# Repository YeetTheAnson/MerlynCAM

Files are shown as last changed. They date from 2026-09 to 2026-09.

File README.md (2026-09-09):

# MerlynCAM

## Introduction
This project was made possible thanks the reverse engineering efforts done by the OpenIPC team! You can check out their supported hardware here: https://openipc.org/supported-hardware/featured and the reference project here: https://oshwlab.com/oshwhub.com/openipc-vtx-ssc338q-30kq

This is my custom action camera, the MerlynCAM! This project was made to record HD footage on my FPV drones. It records video at 1080p@90, 1440p@60 and 4k@20. It also includes a BMI270 gyro to log motion data at 150Hz for Gyroflow video stabilization, and an ICS-43434 I2S microphone to capture propeller noise for the viewer's immersion.

The MerlynCAM is powered by the Sigmastar SSC338Q SOC. It is easy to use and includes a low power microcontroller onboard to manage the LED indicators, buttons, and power saving modes. There is only one button used for powering the camera on and off and starting and stopping recordings. The microcontroller handles the rest of the quality of life features in the background, such as battery level monitoring and auto power on when external voltage is detected in FPV mode. It also has an internal 1S battery with a BQ25606 charging circuit, so it can be used like a normal action cam or with the batteries removed to save weight on a drone.

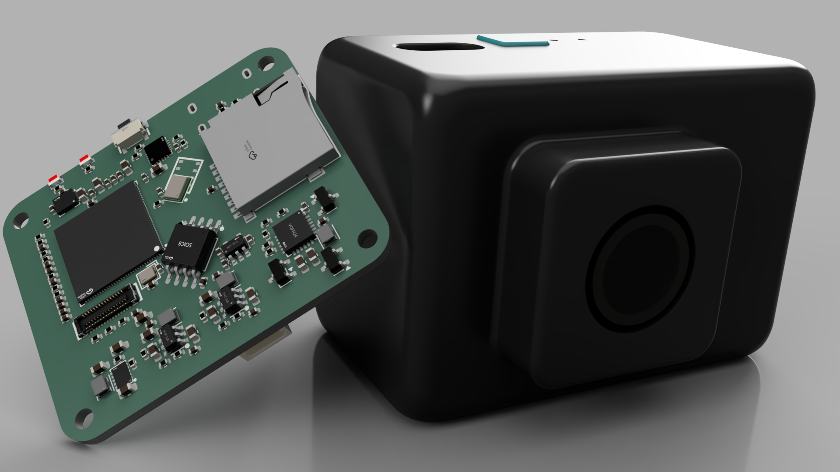
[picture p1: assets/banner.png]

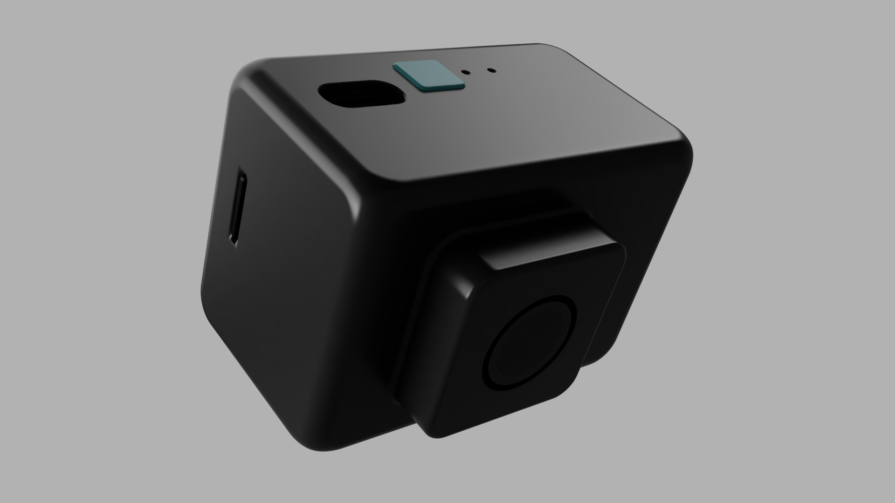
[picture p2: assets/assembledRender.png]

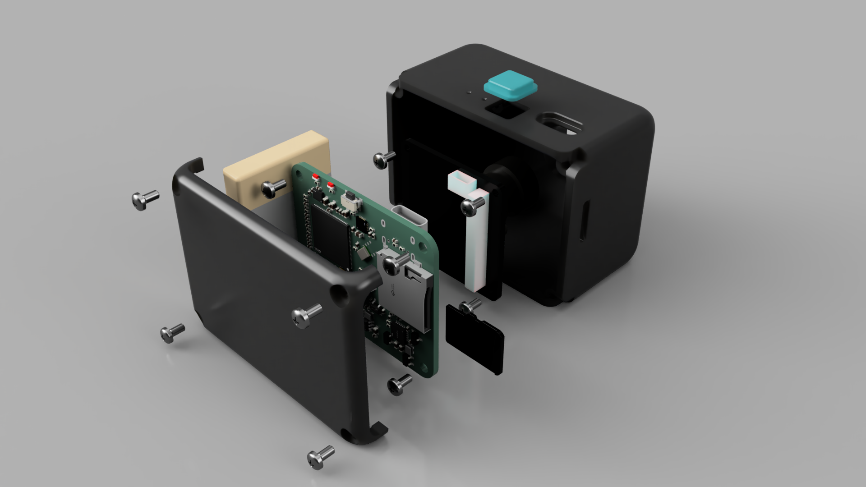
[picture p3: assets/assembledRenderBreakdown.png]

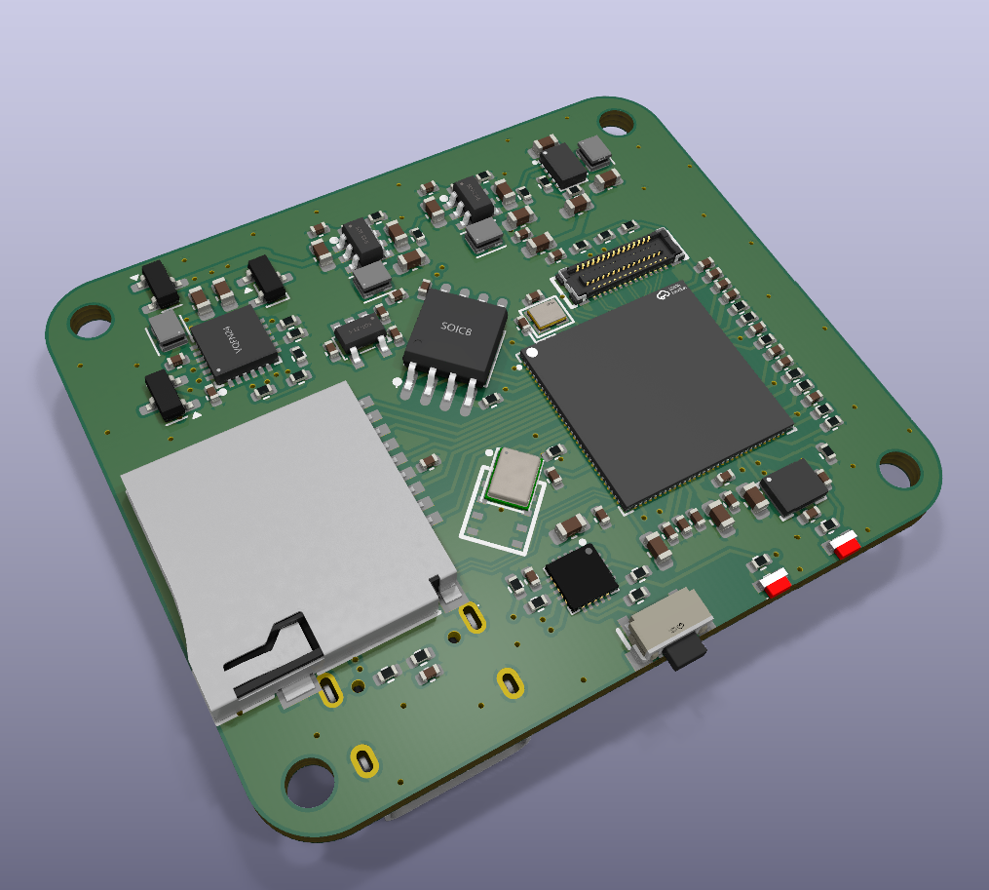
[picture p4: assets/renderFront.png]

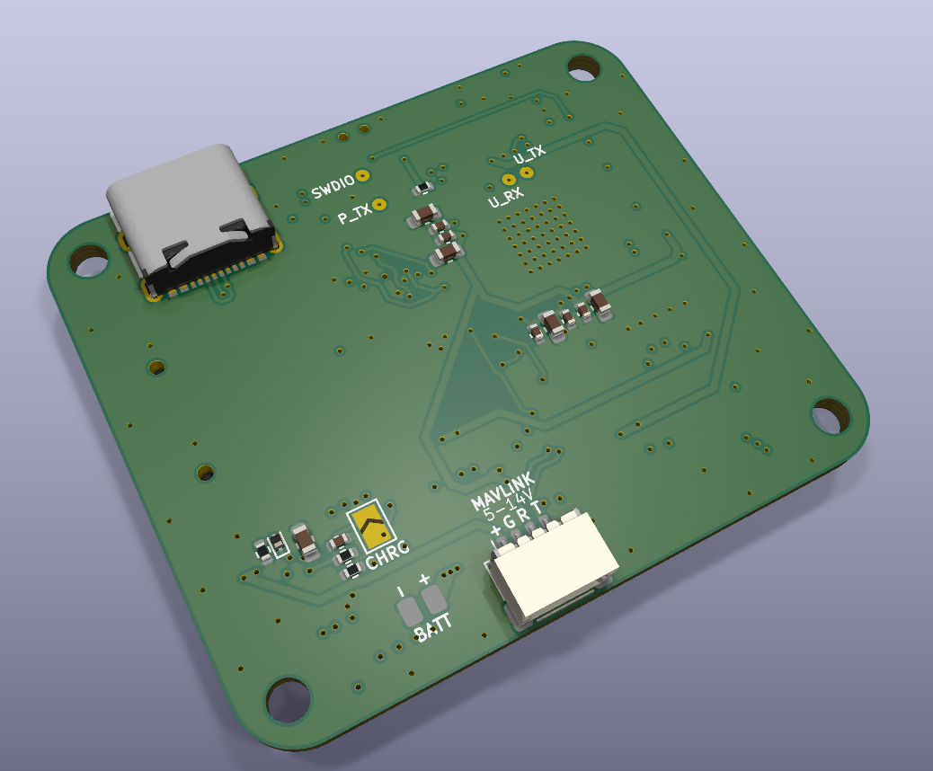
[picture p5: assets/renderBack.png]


## User Guide
The MerlynCAM is operated using a single button and it shows charge status and battery levels using a White LED

### Power & Recording Control
- **Power On:** Press the button once, then press and hold for 2 seconds. The White LED will blink rapidly while holding, then turn solid to indicate it is booting. Release the button afterwards.

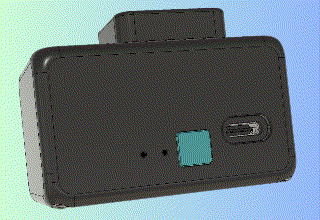
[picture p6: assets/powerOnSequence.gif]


> [!TIP]
> The camera will refuse to power on if the battery is below 5%

- **Power Off:** Press and hold the button for 4 seconds. The White LED will blink rapidly after 2 seconds, then blink twice and turn off.

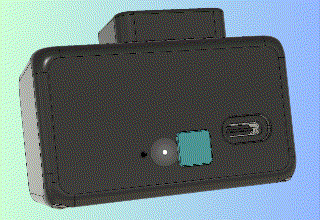
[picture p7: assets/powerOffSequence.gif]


- **Start/Stop Recording:** While the camera is powered on, hold the button for 1 second to start recording. Hold for 1 second again to stop recording.



### Battery Level Checking
While powered off, press the button once. The White LED will blink to indicate the current charge level:

- **\>95%:** 4 normal blinks + 3 rapid blinks



- **80-95%** 4 blinks



- **60-79%:** 3 blinks



- **40-59%:** 2 blinks



- **20-39%:** 1 blink



- **\< 5%:** 3 rapid blinks



### Passive Indicator
- **Charging:** The white LED will pulse slowly while charging. Once fully charged, it will remain solid until the power is disconnected

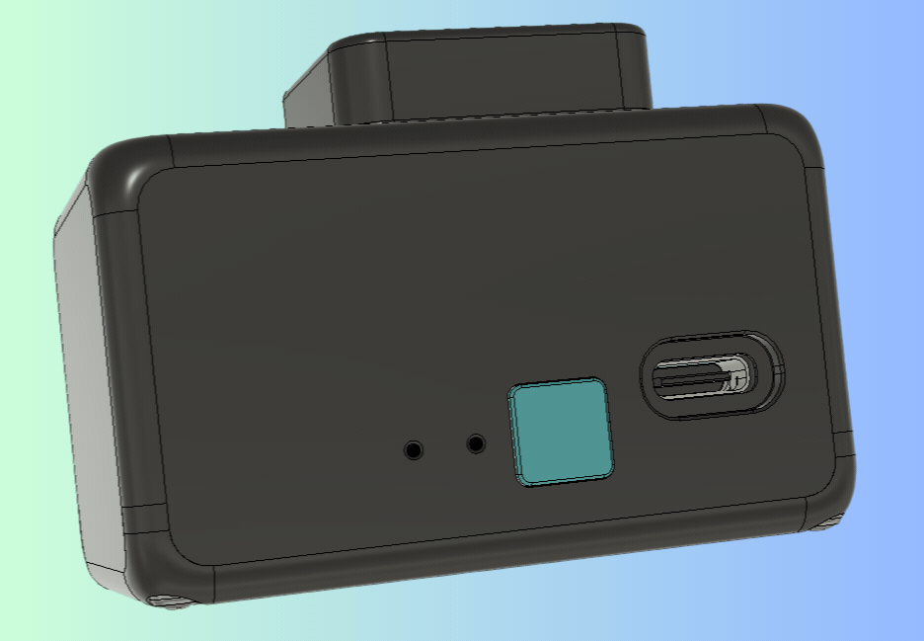
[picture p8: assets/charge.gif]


- **Battery Status:** The White LED automatically flashes the current battery percentage every 3.5 seconds

> [!IMPORTANT]
> Bridge the CHRG pad on the PCB if no battery is connected. This is necessary for the battery management IC to output a stable voltage on external power.

## Hardware Specifications
* **SOC:** Sigmastar SSC338Q
* **Camera Interface:** 30 pin mezzanine connector (compatible with Orange Pi 5)
* **IMU:** BMI270 @ I2C
* **Microphone:** ICS-43434 @ I2S
* **Storage:** Micro SD Card slot + W25Q128JVSIQ 16MB NOR Flash
* **Power Management & User Interface:** CH32V003F4U6
* **Battery Management:** BQ25606
* **Power Supply:** TPS63802 buck boost (3.3V), RT8097CHGE buck (1.0V and 1.5V), RT9193-18GB LDO (1.8V)

## Hardware Overview
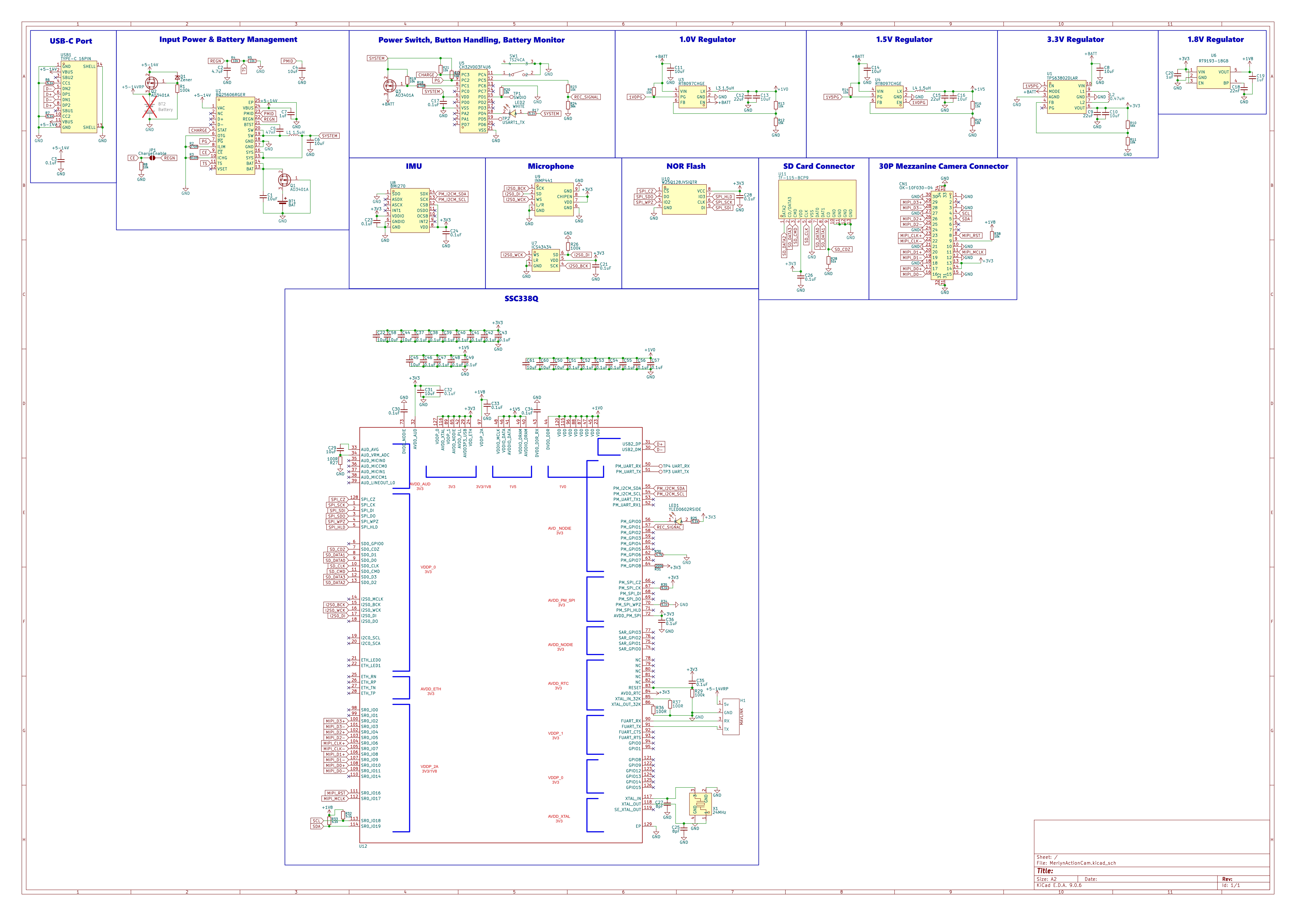
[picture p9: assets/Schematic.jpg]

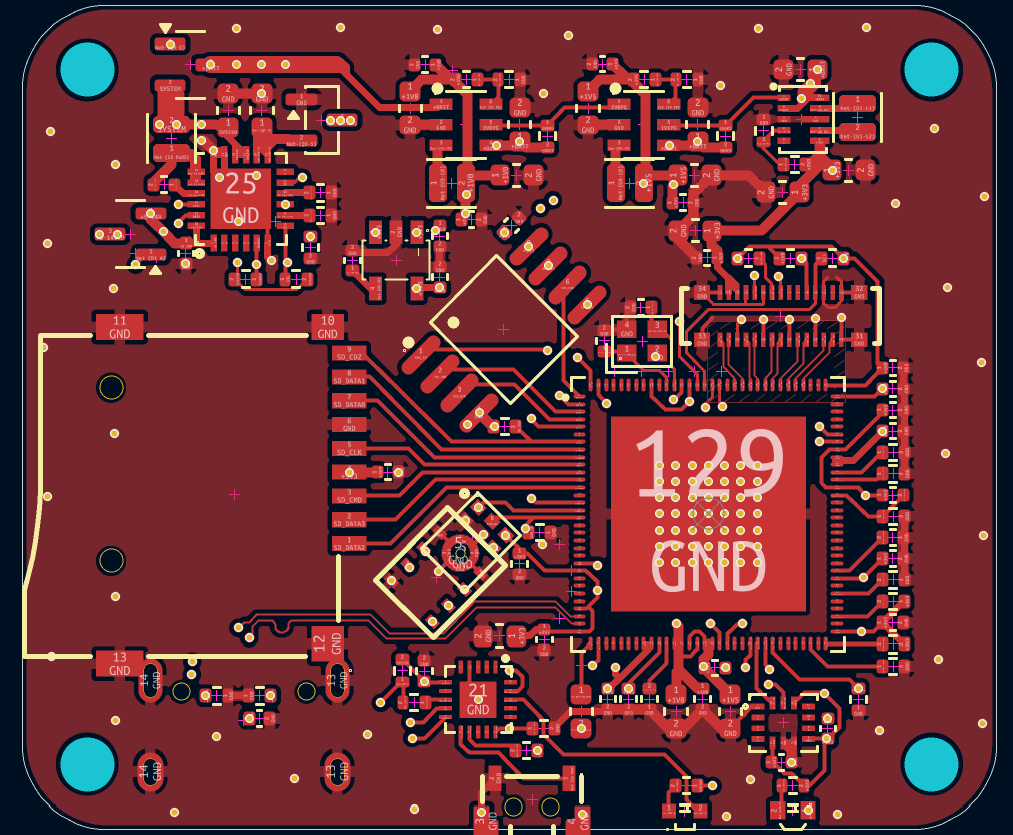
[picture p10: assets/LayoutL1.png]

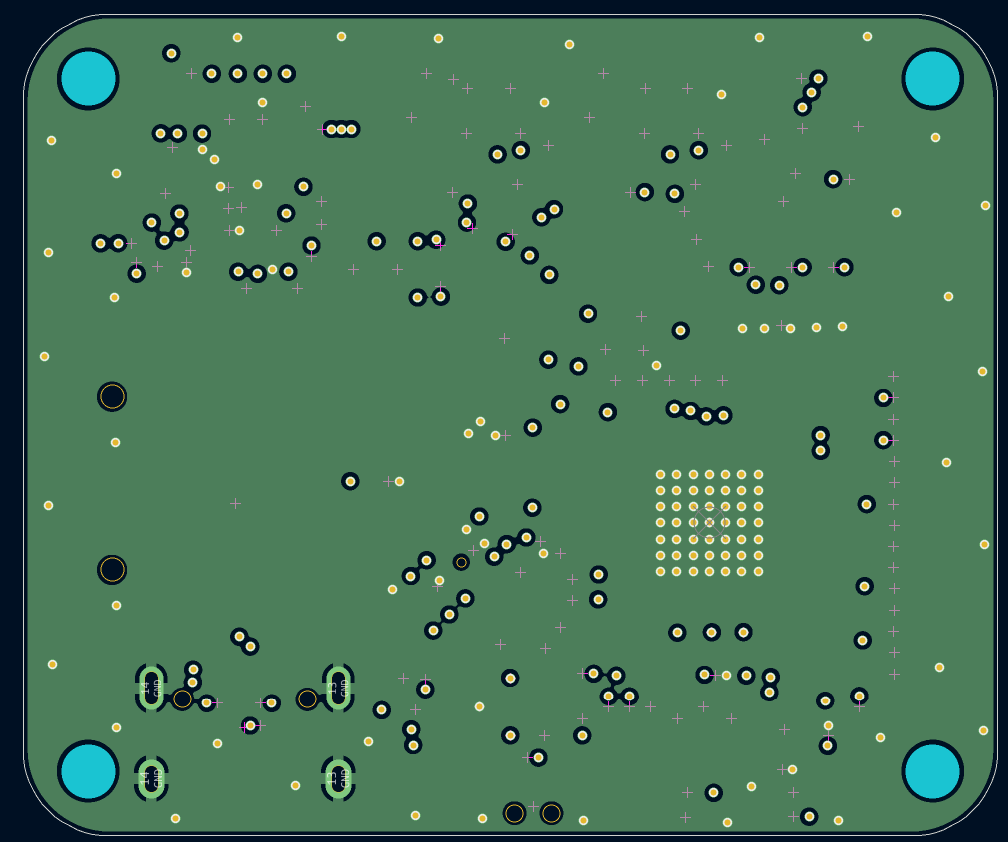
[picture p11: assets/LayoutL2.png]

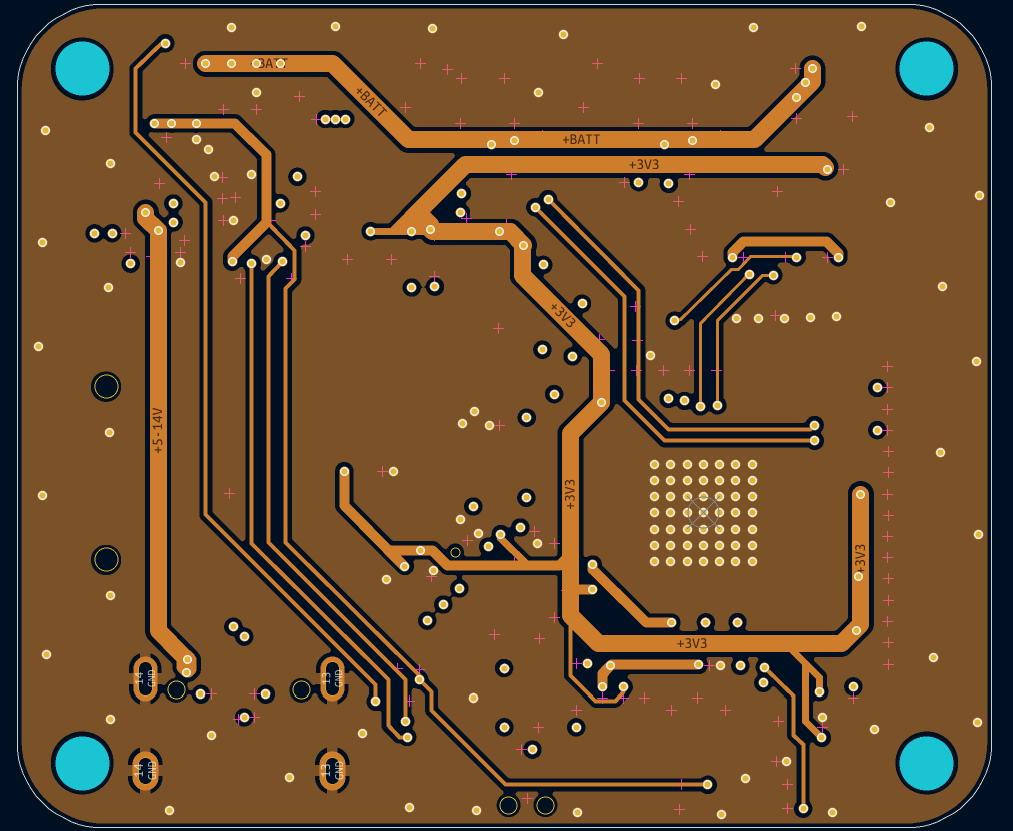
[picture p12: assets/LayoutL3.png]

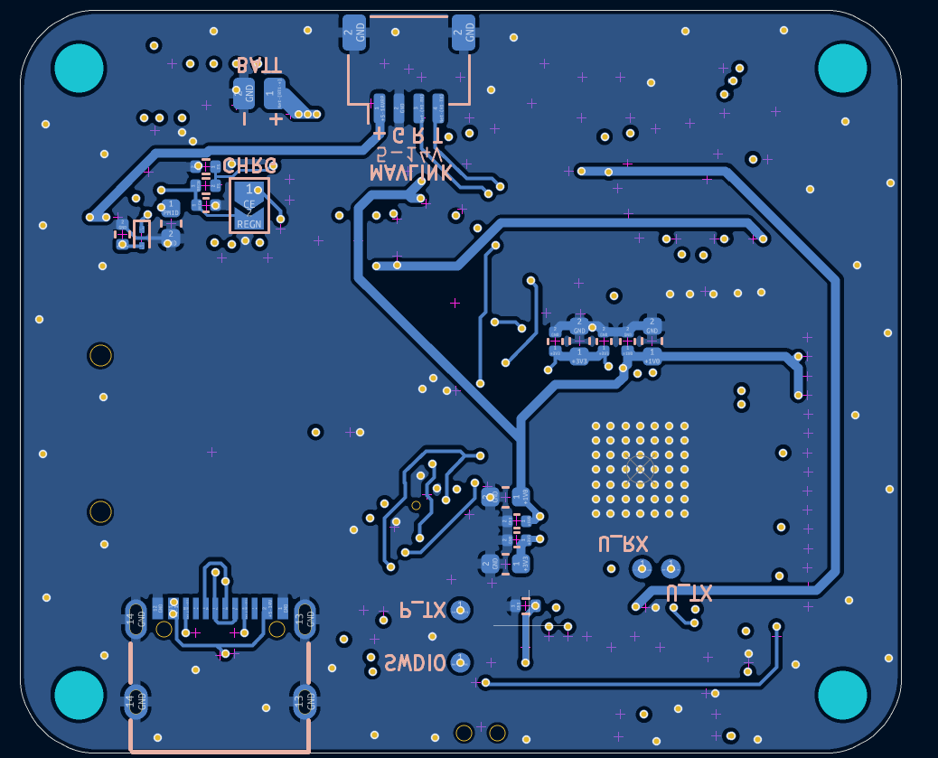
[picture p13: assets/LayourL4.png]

> [!WARNING]
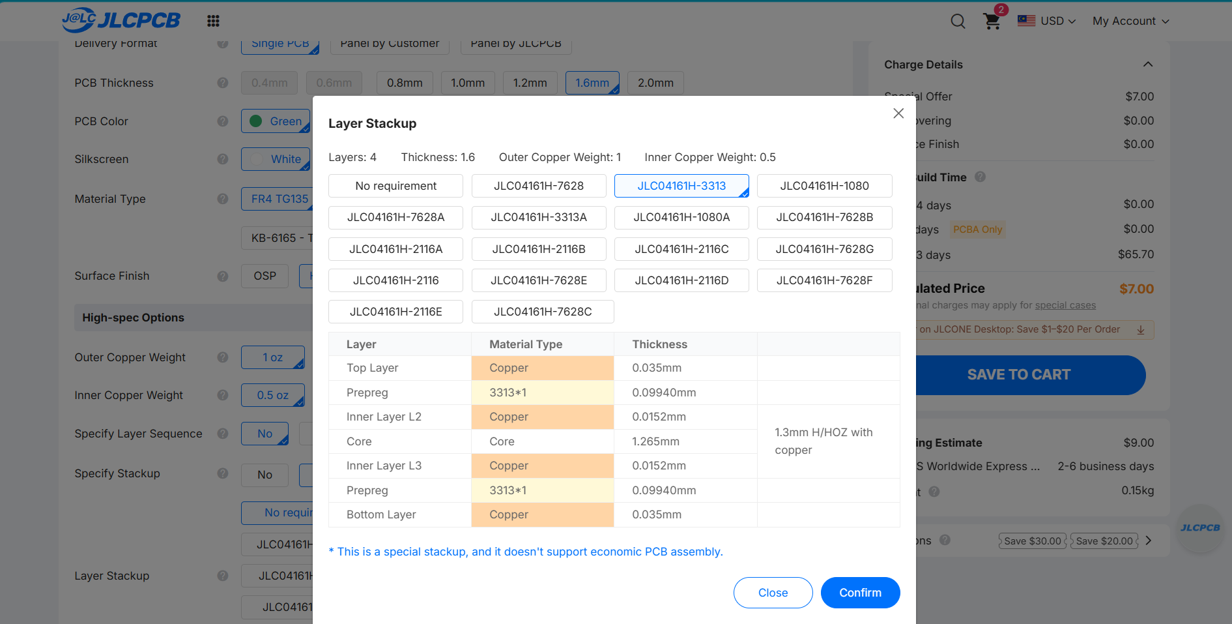
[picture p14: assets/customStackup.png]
> When ordering from JLCPCB, make sure to enable impedance control and use the JLC04161H-3313 Stackup 

## Firmware
Because the SSC338Q is a proprietary chip, it must run the OpenIPC linux environment. Building the firmware requires a linux filesystem (Windows isn't supported)

> [!WARNING]
> At least 20GB of free space is required to build OpenIPC

### How to build the firmware (SSC338Q)
1. Clone the OpenIPC [firmware repository](https://github.com/openipc/firmware)
2. Run `make` and select the infinity6e architecture on the TUI.
3. Navigate to `output/build/linux-custom/arch/arm/boot/dts/` and replace `infinity6e-ssc012b-s01a.dts` with [infinity6e-ssc012b-s01a.dts](https://github.com/YeetTheAnson/MerlynCAM/blob/main/firmware/source/openIPC/infinity6e-ssc012b-s01a.dts).
4. Run `make linux-rebuild` to update the custom DTS changes into the kernel.
5. Navigate to `output/build/images` and extract `openipc.ssc338q-nand-ultimate.tgz` by entering `tar -xzf openipc.ssc338q-nand-ultimate.tgz`
6. Navigate to ssc338q-nand-ultimate and enter the command in your terminal
 `dd if=uImage.ssc338q of=openipc-ssc338q-nor-ultimate-16mb.bin bs=1K seek=384 conv=notrunc` and the binary file should appear

### How to build the firmware (CH32V003)
1. Clone [this repository](https://github.com/YeetTheAnson/MerlynCAM/tree/main) and enter the directory `cd MerlynCAM`
2. Open the `/firmware/source/powerManagement/powerManagement.ino` file in ArduinoIDE
3. Paste `https://alexandermandera.github.io/arduino-wch32v003/package_ch32v003_index.json` into File > Preferences > Additional boards manager URLs
4. Go to boards manager and install `WCH Boards` by Alexander Mandera
5. Click the upload button or Sketch > Export Compiled Binary

### How to flash the firmware (SSC338Q)
The W25Q128 16MB flash chip comes blank from the factory and the openIPC bootloader must be flashed before the operating system is able to boot.
1. Connect the CH341A USB programmer or a [makeshift Arduino programmer](https://controllerstech.com/arduino-w25q-flash-memory/) to flash the binary file to the W25Q128 flash chip. The file can be obtained in [firmware/binaries/(SSC338Q)openipc-nor-ultimate-16mb.bin](https://github.com/YeetTheAnson/MerlynCAM/blob/main/firmware/binaries/(SSC338Q)openipc-nor-ultimate-16mb.bin) or the [OpenIPC repository](https://openipc.org/cameras/vendors/sigmastar/socs/ssc338q/download_full_image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) or compiled locally.

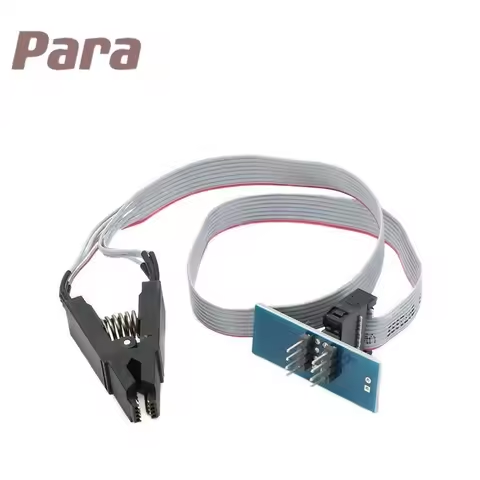
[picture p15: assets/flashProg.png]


### How to flash the firmware (CH32V003)
1. Connect the WCH Link USB adapter to the SWDIO test point
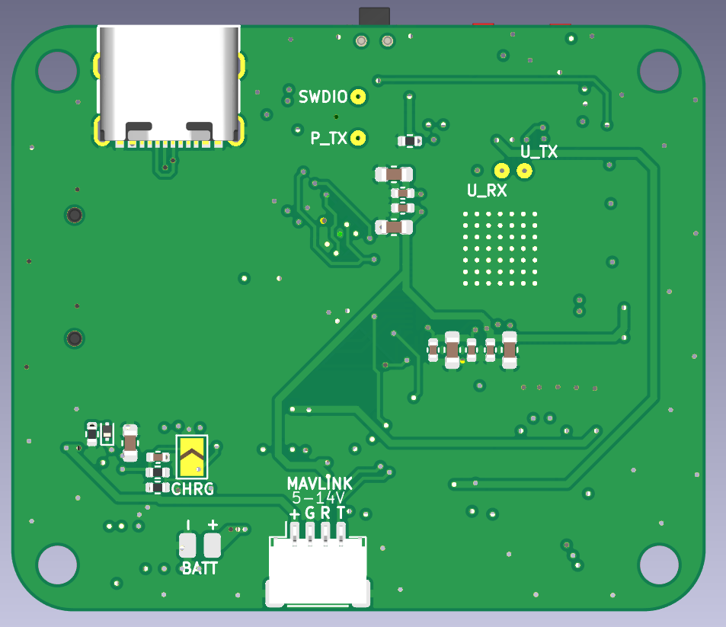
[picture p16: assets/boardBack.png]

2. Connect the USB C port. The MerlynCAM PCB and WCH Link USB adapter must share common ground (e.g. connected to the same laptop)
3. If compiling locally, press the upload button in Arduino IDE. Or use WCH-LinkUtility if flashing the pre compile binary in [powerManagement.hex](https://github.com/YeetTheAnson/MerlynCAM/blob/main/firmware/binaries/%28CH32V003%29powerManagement.hex)

## Assembly

### Component List
* **Shell:**
    - [case.stl](https://github.com/YeetTheAnson/MerlynCAM/blob/main/production/3dPrint/case.stl)
    - [lid.stl](https://github.com/YeetTheAnson/MerlynCAM/blob/main/production/3dPrint/lid.stl)
    - [button.stl](https://github.com/YeetTheAnson/MerlynCAM/blob/main/production/3dPrint/button.stl)
* **PCB:**
    - [MerlynCAM.zip](https://github.com/YeetTheAnson/MerlynCAM/blob/main/production/PCB/MerlynCAM.zip)
* **Camera:** IMX415 camera module for Orange Pi 5 + 30P MIPI cable
* **Fasteners:**
    - 8x M2 6mm Self Tapping Screws
    - 4x M2 4mm Self Tapping Screws
* **Battery:** Generic 500mAh LiPo battery
* **SD Card:** Generic micro SD Card

### Assembly Instructions

1. Place IMX415 camera module in the case and secure with 4x 6mm Self Tapping Screws.

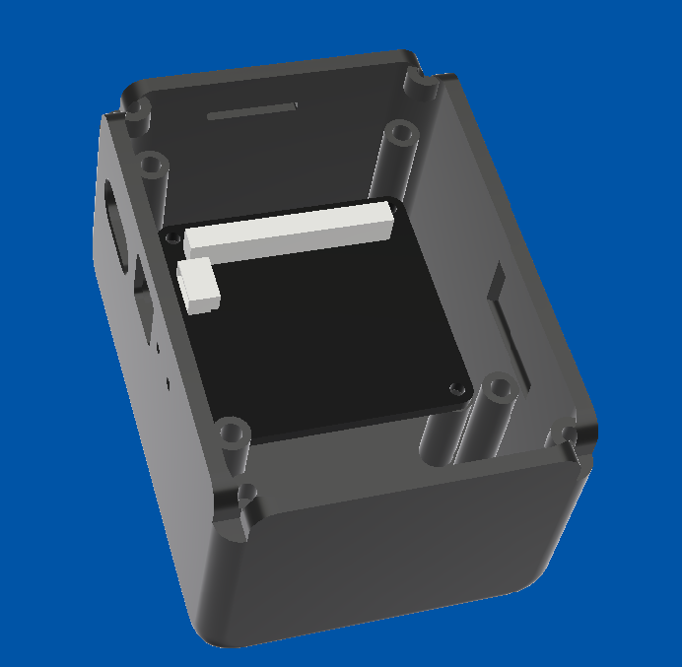
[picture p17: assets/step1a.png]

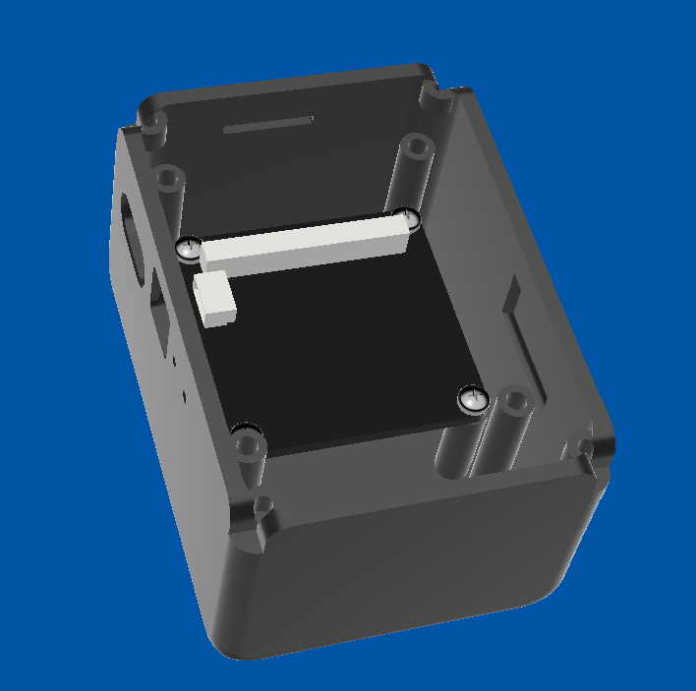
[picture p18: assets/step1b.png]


2. Insert button with the hole side facing up.

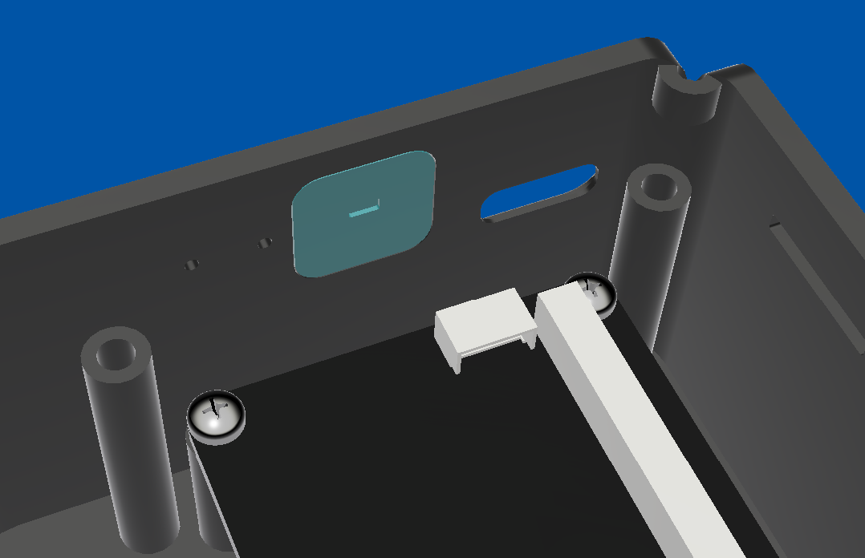
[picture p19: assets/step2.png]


3. Solder the battery wires to designated pads and place the battery and PCB into the case. Route the MIPI cable through the recess of the case wall and connect to the mezzanine connector.

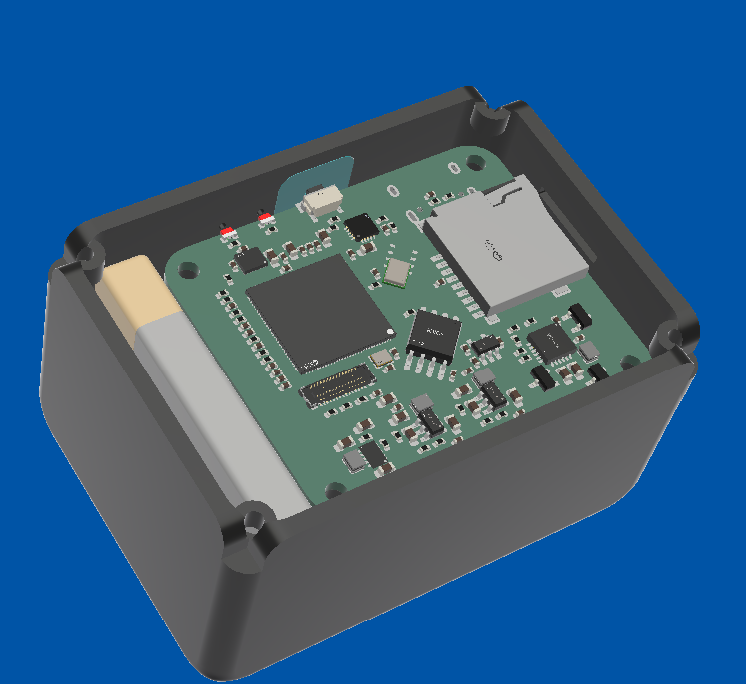
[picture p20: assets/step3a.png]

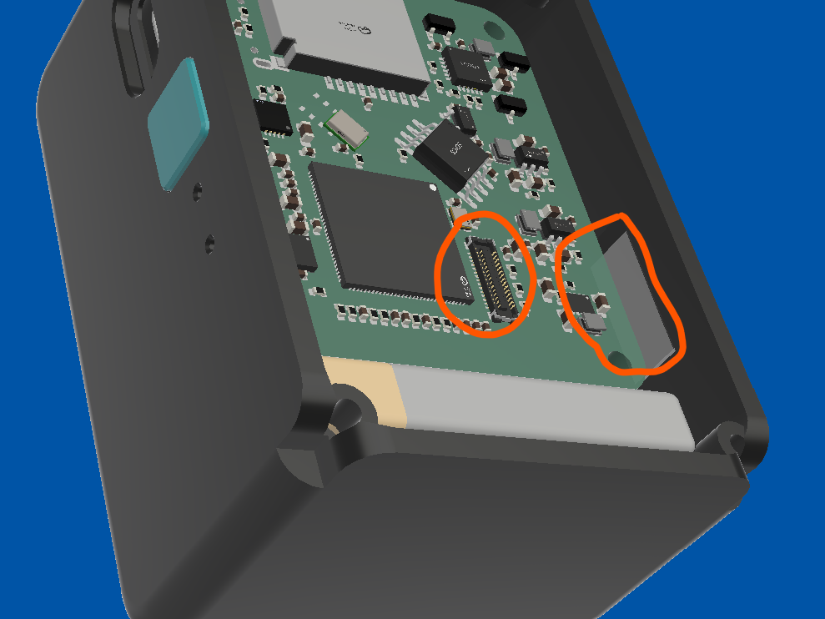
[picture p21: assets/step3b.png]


4. Secure the PCB to the case with 4x 6mm Self Tapping Screws.

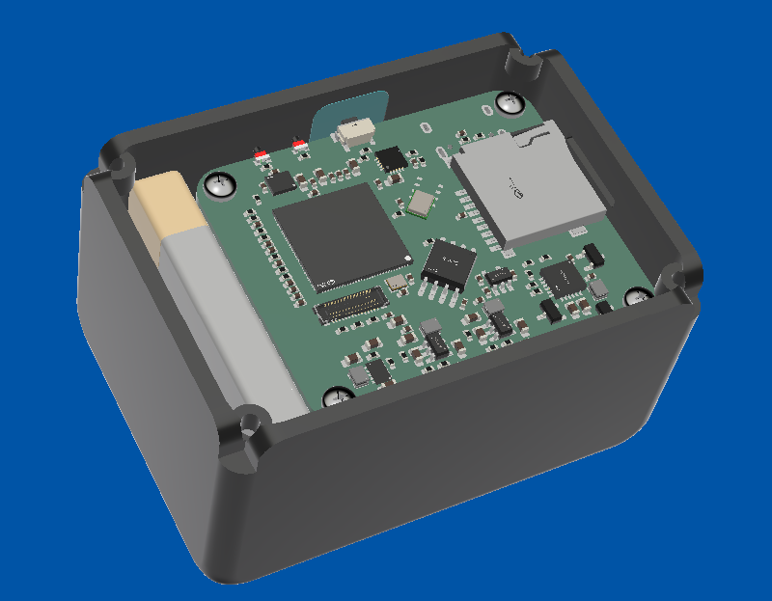
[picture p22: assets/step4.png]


5. Put on the case lid and secure with 4x 4mm Self Tapping Screws.

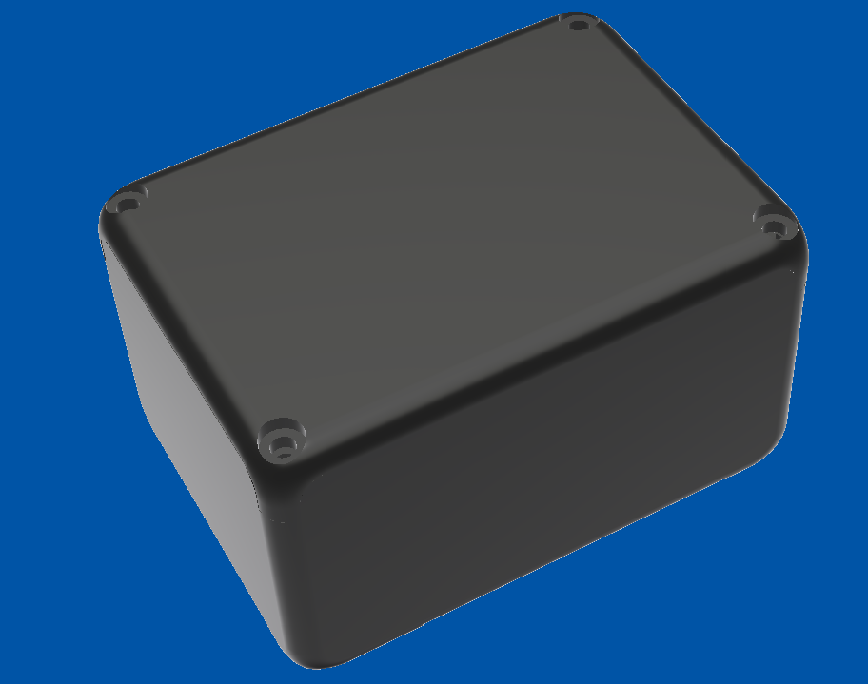
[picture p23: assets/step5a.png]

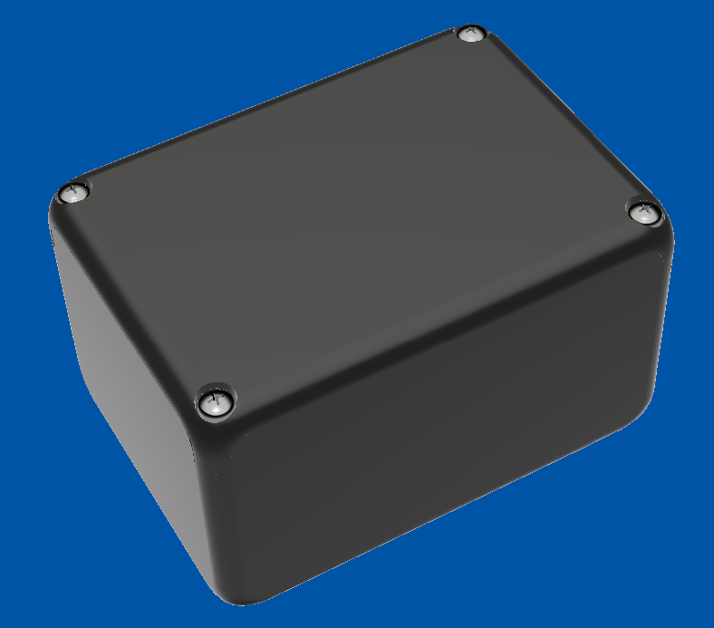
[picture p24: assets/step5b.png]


## Bill of Material
Note: The prices in USD are converted as of 1 September 2026 and may fluctuate. The costs of separate components are cheaper than JLCPCB assembly.

| Category | Item Name | Description | Link | Vendor | Quantity | Total Price (USD) |
|---|---|---|---|---|---:|---:|
| PCB Components | CL10A106MA8NRNC | 10uF 0603 capacitor | [link](https://www.lcsc.com/product-detail/C96446.html) | LCSC | 20 | 1.30 |
| PCB Components | CL05A475MP5NRNC | 4.7uF 0402 capacitor | [link](https://www.lcsc.com/product-detail/C23733.html) | LCSC | 50 | 1.17 |
| PCB Components | CL05B104KB54PNC | 0.1uF 0402 capacitor | [link](https://www.lcsc.com/product-detail/C307331.html) | LCSC | 100 | 0.89 |
| PCB Components | CC0402KRX7R9BB473 | 47nF 0402 capacitor | [link](https://www.lcsc.com/product-detail/C272875.html) | LCSC | 100 | 0.41 |
| PCB Components | CL05A105KA5NQNC | 1uF 0402 capacitor | [link](https://www.lcsc.com/product-detail/C52923.html) | LCSC | 50 | 0.61 |
| PCB Components | CL10A226MQ8NRNC | 22uF 0603 capacitor | [link](https://www.lcsc.com/product-detail/C59461.html) | LCSC | 20 | 0.63 |
| PCB Components | 0402B223K500NT | 22nF 0402 capacitor | [link](https://www.lcsc.com/product-detail/C1532.html) | LCSC | 50 | 0.58 |
| PCB Components | 0402CG8R0C500NT | 8pF 0402 capacitor | [link](https://www.lcsc.com/product-detail/C1578.html) | LCSC | 100 | 0.36 |
| PCB Components | CDZVT2R5.1B | 5.1V Clamp SOD923 zener | [link](https://www.lcsc.com/product-detail/C414245.html) | LCSC | 20 | 0.64 |
| PCB Components | HC-1.0-4PWT | 4P JST-SH connector | [link](https://www.lcsc.com/product-detail/C2845363.html) | LCSC | 5 | 0.47 |
| PCB Components | FTC201610S1R5MBCA | 1.5uH 0806 inductor | [link](https://www.lcsc.com/product-detail/C5832343.html) | LCSC | 10 | 0.98 |
| PCB Components | FTC201610SR47MBCA | 0.47 uH 0806 inductor | [link](https://www.lcsc.com/product-detail/C5832340.html) | LCSC | 10 | 0.98 |
| PCB Components | YLED0602RSIDE | Red 0602 right angle LED | [link](https://www.lcsc.com/product-detail/C49446796.html) | LCSC | 20 | 0.49 |
| PCB Components | YLED0602WSIDE | White 0602 right angle LED | [link](https://www.lcsc.com/product-detail/C46635136.html) | LCSC | 50 | 0.99 |
| PCB Components | AO3401A | P channel MOSFET | [link](https://www.lcsc.com/product-detail/C15127.html) | LCSC | 5 | 0.49 |
| PCB Components | 0402WGF1003TCE | 100k 0402 resistor | [link](https://www.lcsc.com/product-detail/C25741.html) | LCSC | 100 | 0.28 |
| PCB Components | FRC0402F2700TS | 270R 0402 resistor | [link](https://www.lcsc.com/product-detail/C2909342.html) | LCSC | 100 | 0.25 |
| PCB Components | FRC0402F9100TS | 910R 0402 resistor | [link](https://www.lcsc.com/product-detail/C2909392.html) | LCSC | 100 | 0.18 |
| PCB Components | 0402WGF1002TCE | 10k 0402 resistor | [link](https://www.lcsc.com/product-detail/C25744.html) | LCSC | 100 | 0.31 |
| PCB Components | 0402WGF5101TCE | 5.1k 0402 resistor | [link](https://www.lcsc.com/product-detail/C25905.html) | LCSC | 100 | 0.26 |
| PCB Components | 0402WGF5602TCE | 56k 0402 resistor | [link](https://www.lcsc.com/product-detail/C25796.html) | LCSC | 100 | 0.68 |
| PCB Components | 0402WGF1502TCE | 15k 0402 resistor | [link](https://www.lcsc.com/product-detail/C25756.html) | LCSC | 100 | 0.58 |
| PCB Components | FRC0402F3602TS | 36k 0402 resistor | [link](https://www.lcsc.com/product-detail/C2930004.html) | LCSC | 100 | 0.19 |
| PCB Components | 0402WGF1000TCE | 100R 0402 resistor | [link](https://www.lcsc.com/product-detail/C25076.html) | LCSC | 100 | 0.77 |
| PCB Components | 0402WGF5102TCE | 51k 0402 resistor | [link](https://www.lcsc.com/product-detail/C25794.html) | LCSC | 100 | 0.19 |
| PCB Components | 0402WGF4701TCE | 4.7k 0402 resistor | [link](https://www.lcsc.com/product-detail/C25900.html) | LCSC | 100 | 0.29 |
| PCB Components | 0402WGF2003TCE | 200k 0402 resistor | [link](https://www.lcsc.com/product-detail/C25764.html) | LCSC | 100 | 0.32 |
| PCB Components | TS24CA | Right angle button | [link](https://www.lcsc.com/product-detail/C393942.html) | LCSC | 20 | 0.51 |
| PCB Components | TPS63802DLAR | Buck boost converter | [link](https://www.lcsc.com/product-detail/C2845237.html) | LCSC | 2 | 2.05 |
| PCB Components | BQ25606RGER | Battery charge and management | [link](https://www.lcsc.com/product-detail/C374063.html) | LCSC | 1 | 1.63 |
| PCB Components | RT8097CHGE | Buck converter | [link](https://www.lcsc.com/product-detail/C3031673.html) | LCSC | 5 | 0.80 |
| PCB Components | CH32V003F4U6 | CH32 for interface and power management | [link](https://www.lcsc.com/product-detail/C5299908.html) | LCSC | 5 | 1.58 |
| PCB Components | RT9193-18GB | 1.8V Linear LDO regulator | [link](https://www.lcsc.com/product-detail/C27416.html) | LCSC | 5 | 0.83 |
| PCB Components | ICS-43434 | I2S MEMS microphone | [link](https://www.lcsc.com/product-detail/C5656610.html) | LCSC | 1 | 4.13 |
| PCB Components | BMI270 | IMU | [link](https://www.lcsc.com/product-detail/C2836813.html) | LCSC | 1 | 3.25 |
| PCB Components | W25Q128JVSIQ | 16 MB NOR flash | [link](https://www.lcsc.com/product-detail/C97521.html) | LCSC | 1 | 2.62 |
| PCB Components | TF-115-BCP9 | SD card connector | [link](https://www.lcsc.com/product-detail/C720505.html) | LCSC | 5 | 0.49 |
| PCB Components | TYPE-C 16PIN 2MD(073) | TYPE C Connector | [link](https://www.lcsc.com/product-detail/C2765186.html) | LCSC | 20 | 1.49 |
| PCB Components | T201624MBBCE2X | 24MHz 2016 crystal resonator | [link](https://www.lcsc.com/product-detail/C7303340.html) | LCSC | 10 | 0.71 |
| PCB Components | LCSC Shipping | 4PX | - | 4PX | 1 | 5.48 |
| PCB | PCB | Bare PCB | - | JLCPCB | 1 | 2.00 |
| PCB | Stencil | Stencil | - | JLCPCB | 1 | 6.36 |
| PCB | JLCPCB Shipping | Shipping | - | E-POST | 1 | 6.68 |
| Parts | OK-10F030-04 | 30P 0.4mm Mezzanine connector | [link](https://www.aliexpress.com/item/1005008289234567.html) | AliExpress | 1 | 2.09 |
| Parts | SSC338Q | Main recording SOC | [link](https://www.aliexpress.com/item/1005009947110808.html) | AliExpress | 1 | 16.99 |
| Parts | IMX415 camera module | IMX415 camera module 140 FOV | [link](https://www.aliexpress.com/item/1005009005078802.html) | AliExpress | 1 | 32.69 |
| Parts | AliExpress Shipping | Shipping | - | AliExpress | 1 | 9.74 |

### **Grand Total:** \$117.41

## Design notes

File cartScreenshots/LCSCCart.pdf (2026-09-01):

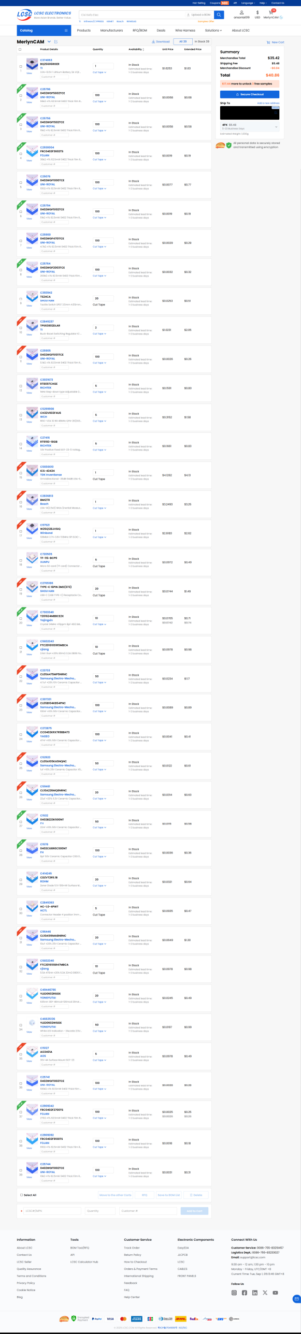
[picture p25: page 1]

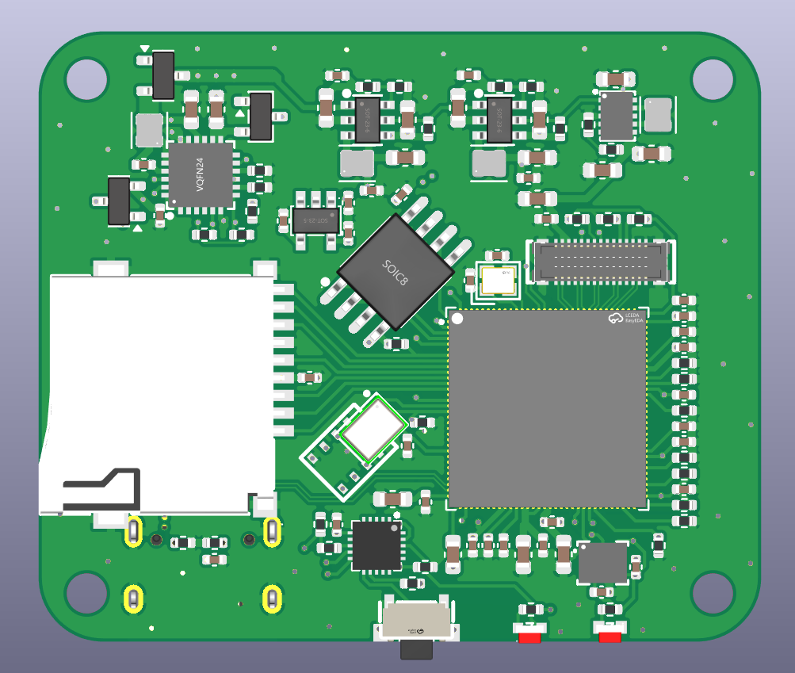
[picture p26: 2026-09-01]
assets/boardFront.png

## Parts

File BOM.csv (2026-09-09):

Category | Item Name | Description | Link | Vendor | Quantity | Total Price (USD)
PCB Components | CL10A106MA8NRNC | 10uF 0603 capacitor | https://www.lcsc.com/product-detail/C96446.html | LCSC | 20 | 1.30
PCB Components | CL05A475MP5NRNC | 4.7uF 0402 capacitor | https://www.lcsc.com/product-detail/C23733.html | LCSC | 50 | 1.17
PCB Components | CL05B104KB54PNC | 0.1uF 0402 capacitor | https://www.lcsc.com/product-detail/C307331.html | LCSC | 100 | 0.89
PCB Components | CC0402KRX7R9BB473 | 47nF 0402 capacitor | https://www.lcsc.com/product-detail/C272875.html | LCSC | 100 | 0.41
PCB Components | CL05A105KA5NQNC | 1uF 0402 capacitor | https://www.lcsc.com/product-detail/C52923.html | LCSC | 50 | 0.61
PCB Components | CL10A226MQ8NRNC | 22uF 0603 capacitor | https://www.lcsc.com/product-detail/C59461.html | LCSC | 20 | 0.63
PCB Components | 0402B223K500NT | 22nF 0402 capacitor | https://www.lcsc.com/product-detail/C1532.html | LCSC | 50 | 0.58
PCB Components | 0402CG8R0C500NT | 8pF 0402 capacitor | https://www.lcsc.com/product-detail/C1578.html | LCSC | 100 | 0.36
PCB Components | CDZVT2R5.1B | 5.1V Clamp SOD923 zener | https://www.lcsc.com/product-detail/C414245.html | LCSC | 20 | 0.64
PCB Components | HC-1.0-4PWT | 4P JST-SH connector | https://www.lcsc.com/product-detail/C2845363.html | LCSC | 5 | 0.47
PCB Components | FTC201610S1R5MBCA | 1.5uH 0806 inductor | https://www.lcsc.com/product-detail/C5832343.html | LCSC | 10 | 0.98
PCB Components | FTC201610SR47MBCA | 0.47 uH 0806 inductor | https://www.lcsc.com/product-detail/C5832340.html | LCSC | 10 | 0.98
PCB Components | YLED0602RSIDE | Red 0602 right angle LED | https://www.lcsc.com/product-detail/C49446796.html | LCSC | 20 | 0.49
PCB Components | YLED0602WSIDE | White 0602 right angle LED | https://www.lcsc.com/product-detail/C46635136.html | LCSC | 50 | 0.99
PCB Components | AO3401A | P channel MOSFET | https://www.lcsc.com/product-detail/C15127.html | LCSC | 5 | 0.49
PCB Components | 0402WGF1003TCE | 100k 0402 resistor | https://www.lcsc.com/product-detail/C25741.html | LCSC | 100 | 0.28
PCB Components | FRC0402F2700TS | 270R 0402 resistor | https://www.lcsc.com/product-detail/C2909342.html | LCSC | 100 | 0.25
PCB Components | FRC0402F9100TS | 910R 0402 resistor | https://www.lcsc.com/product-detail/C2909392.html | LCSC | 100 | 0.18
PCB Components | 0402WGF1002TCE | 10k 0402 resistor | https://www.lcsc.com/product-detail/C25744.html | LCSC | 100 | 0.31
PCB Components | 0402WGF5101TCE | 5.1k 0402 resistor | https://www.lcsc.com/product-detail/C25905.html | LCSC | 100 | 0.26
PCB Components | 0402WGF5602TCE | 56k 0402 resistor | https://www.lcsc.com/product-detail/C25796.html | LCSC | 100 | 0.68
PCB Components | 0402WGF1502TCE | 15k 0402 resistor | https://www.lcsc.com/product-detail/C25756.html | LCSC | 100 | 0.58
PCB Components | FRC0402F3602TS | 36k 0402 resistor | https://www.lcsc.com/product-detail/C2930004.html | LCSC | 100 | 0.19
PCB Components | 0402WGF1000TCE | 100R 0402 resistor | https://www.lcsc.com/product-detail/C25076.html | LCSC | 100 | 0.77
PCB Components | 0402WGF5102TCE | 51k 0402 resistor | https://www.lcsc.com/product-detail/C25794.html | LCSC | 100 | 0.19
PCB Components | 0402WGF4701TCE | 4.7k 0402 resistor | https://www.lcsc.com/product-detail/C25900.html | LCSC | 100 | 0.29
PCB Components | 0402WGF2003TCE | 200k 0402 resistor | https://www.lcsc.com/product-detail/C25764.html | LCSC | 100 | 0.32
PCB Components | TS24CA | Right angle button | https://www.lcsc.com/product-detail/C393942.html | LCSC | 20 | 0.51
PCB Components | TPS63802DLAR | Buck boost converter | https://www.lcsc.com/product-detail/C2845237.html | LCSC | 2 | 2.05
PCB Components | BQ25606RGER | Battery charge and management | https://www.lcsc.com/product-detail/C374063.html | LCSC | 1 | 1.63
PCB Components | RT8097CHGE | Buck converter | https://www.lcsc.com/product-detail/C3031673.html | LCSC | 5 | 0.80
PCB Components | CH32V003F4U6 | CH32 for interface and power management | https://www.lcsc.com/product-detail/C5299908.html | LCSC | 5 | 1.58
PCB Components | RT9193-18GB | 1.8V Linear LDO regulator | https://www.lcsc.com/product-detail/C27416.html | LCSC | 5 | 0.83
PCB Components | ICS-43434 | I2S MEMS microphone | https://www.lcsc.com/product-detail/C5656610.html | LCSC | 1 | 4.13
PCB Components | BMI270 | IMU | https://www.lcsc.com/product-detail/C2836813.html | LCSC | 1 | 3.25
PCB Components | W25Q128JVSIQ | 16 MB NOR flash | https://www.lcsc.com/product-detail/C97521.html | LCSC | 1 | 2.62
PCB Components | TF-115-BCP9 | SD card connector | https://www.lcsc.com/product-detail/C720505.html | LCSC | 5 | 0.49
PCB Components | TYPE-C 16PIN 2MD(073) | TYPE C Connector | https://www.lcsc.com/product-detail/C2765186.html | LCSC | 20 | 1.49
PCB Components | T201624MBBCE2X | 24MHz 2016 crystal resonator | https://www.lcsc.com/product-detail/C7303340.html | LCSC | 10 | 0.71
PCB Components | LCSC Shipping | 4PX | - | 4PX | 1 | 5.48
PCB | PCB | Bare PCB | - | JLCPCB | 1 | 2.00
PCB | Stencil | Stencil | - | JLCPCB | 1 | 6.36
PCB | JLCPCB Shipping | Shipping | - | E-POST | 1 | 6.68
Parts | OK-10F030-04 | 30P 0.4mm Mezzanine connector | https://www.aliexpress.com/item/1005008289234567.html | AliExpress | 1 | 2.09
Parts | SSC338Q | Main recording SOC | https://www.aliexpress.com/item/1005009947110808.html | AliExpress | 1 | 16.99
Parts | IMX415 camera module | IMX415 camera module 140 FOV | https://www.aliexpress.com/item/1005009005078802.html | AliExpress | 1 | 32.69
Parts | AliExpress Shipping | Shipping | - | AliExpress | 1 | 9.74
Grand Total | 117.41

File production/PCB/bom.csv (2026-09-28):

Designator | Footprint | Quantity | Value | LCSC Part #
BT1 | Battery | 1 | BAT
C1, C10, C11, C13, C14, C16, C22, C29, C31, C4, C44, C45, C50, C58, C6, C60, C61, C8 | 0603 | 18 | 10uF | C96446
C12, C15, C9 | 0603 | 3 | 22uF | C59461
C17, C21, C23, C24, C26, C28, C3, C30, C32, C33, C34, C35, C36, C37, C38, C39, C40, C41, C42, C43, C46, C47, C48, C49, C51, C52, C53, C54, C55, C56, C57 | 0402 | 31 | 0.1uF | C307331
C18 | 0402 | 1 | 22nF | C1532
C19, C20, C7 | 0402 | 3 | 1uF | C52923
C2 | 0402 | 1 | 4.7uF | C23733
C25, C27 | 0402 | 2 | 8pF | C1578
C5 | 0402 | 1 | 47nF | C272875
CN1 | CONN-SMD_30P-P0.40_OK-10F030-04-A | 1 | OK-10F030-04 | C9900021743
D1 | D_SOD-923 | 1 | Zener | C414245
H1 | JST_SH_SM04B-SRSS-TB_1x04-1MP_P1.00mm_Horizontal | 1 | ~ | C2845363
L1, L3, L4 | L_Changjiang_FTC201610S | 3 | 1.5uH | C5832343
L2 | L_Changjiang_FTC201610S | 1 | 0.47uH | C5832340
LED1 | LED-SMD_L1.6-W1.1-RD | 1 | YLED0602RSIDE | C49446796
LED2 | LED-SMD_L1.6-W1.1-R-RD_WHITE | 1 | WHITE | C46635136
Q1, Q2, Q3 | SOT-23 | 3 | AO3401A | C15127
R1, R26, R29 | 0402 | 3 | 100k | C25741
R10 | 0402 | 1 | 56k | C25796
R11, R13, R14, R15, R19, R20, R21, R22, R23, R38, R4, R5, R8, R9 | 0402 | 14 | 10k | C25744
R12, R16 | 0402 | 2 | 15k | C25756
R17, R25, R32, R33, R34, R35, R39, R40, R6, R7 | 0402 | 10 | 5.1k | C25905
R18, R2 | 0402 | 2 | 270R | C2909342
R24 | 0402 | 1 | 36k | C2930004
R27, R36, R37 | 0402 | 3 | 100R | C25076
R28 | 0402 | 1 | 51k | C25794
R3 | 0402 | 1 | 910R | C2909392
R30 | 0402 | 1 | 4.7k | C25900
R31 | 0402 | 1 | 200k | C25764
SW1 | SW-SMD_2P-TS24CA | 1 | TS24CA | C393942
TP1 | TestPoint | 1 | SWDIO
TP10 | TestPoint | 1 | 3V3
TP11 | TestPoint | 1 | 1V8
TP12 | TestPoint | 1 | GND
TP13 | TestPoint | 1 | ETH_RN
TP14 | TestPoint | 1 | ETH_RP
TP15 | TestPoint | 1 | ETH_TN
TP16 | TestPoint | 1 | ETH_TP
TP2 | TestPoint | 1 | USART1_TX
TP3 | TestPoint | 1 | UART_TX
TP4 | TestPoint | 1 | UART_RX
TP5 | TestPoint | 1 | USBD+
TP6 | TestPoint | 1 | USBD-
TP7 | TestPoint | 1 | +5-14V
TP8 | TestPoint | 1 | 1V0
TP9 | TestPoint | 1 | 1V5
U1 | VSON-10_L3.0-W2.0-P0.50-TL | 1 | TPS63802DLAR | C2845237
U10 | SOIC-8_L5.3-W5.3-P1.27-LS8.0-BL | 1 | W25Q128JVSIQTR | C97521
U11 | TF-SMD_TF-115-BCP9 | 1 | TF-115-BCP9 | C720505
U12 | QFN128_12.3_12.3 | 1 | ~
U2 | VQFN-24_L4.0-W4.0-P0.50-TL-EP2.8 | 1 | BQ25606RGER | C374063
U3, U4 | SOT-23-6_L2.9-W1.6-P0.95-LS2.8-BL | 2 | RT8097CHGE | C3031673
U5 | QFN-20_L3.0-W3.0-P0.40-TL-EP1.7 | 1 | CH32V003F4U6 | C5299908
U6 | SOT-23-5_L3.0-W1.7-P0.95-LS2.8-BR | 1 | RT9193-18GB | C27416
U7 | MIC-SMD_6P-L3.5-W2.7-P0.90-BL | 1 | ICS43434 | C5656610
U8 | LGA-14_L3.0-W2.5-P0.50-BR | 1 | BMI270 | C2836813
U9 | MIC-SMD_INMP441 | 1 | INMP441 | C5438445
USB1 | USB-C-SMD_TYPE-C-6PIN-2MD-073 | 1 | TYPE-C 16PIN | C2765186
X1 | CRYSTAL-SMD_4P-L2.0-W1.6-BL | 1 | 24MHz | C7303340

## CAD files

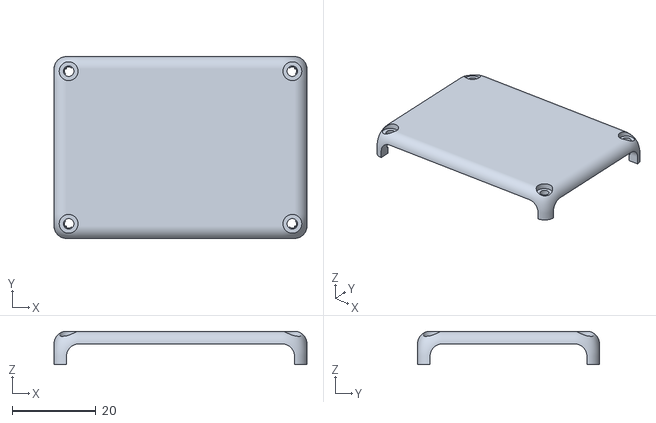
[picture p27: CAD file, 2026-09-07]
production/3dPrint/lid.stl
60.5 x 43.5 x 8.00

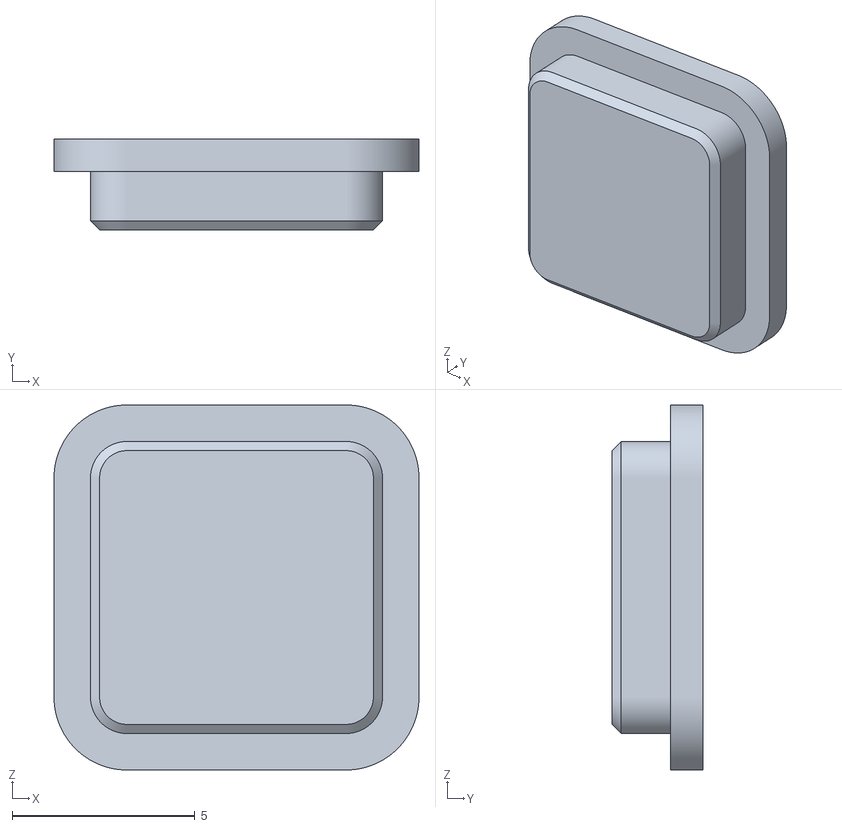
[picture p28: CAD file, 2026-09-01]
production/3dPrint/button.stl
10.0 x 2.50 x 10.00

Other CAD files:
CAD/MerlynCAM_Assembled.f3z

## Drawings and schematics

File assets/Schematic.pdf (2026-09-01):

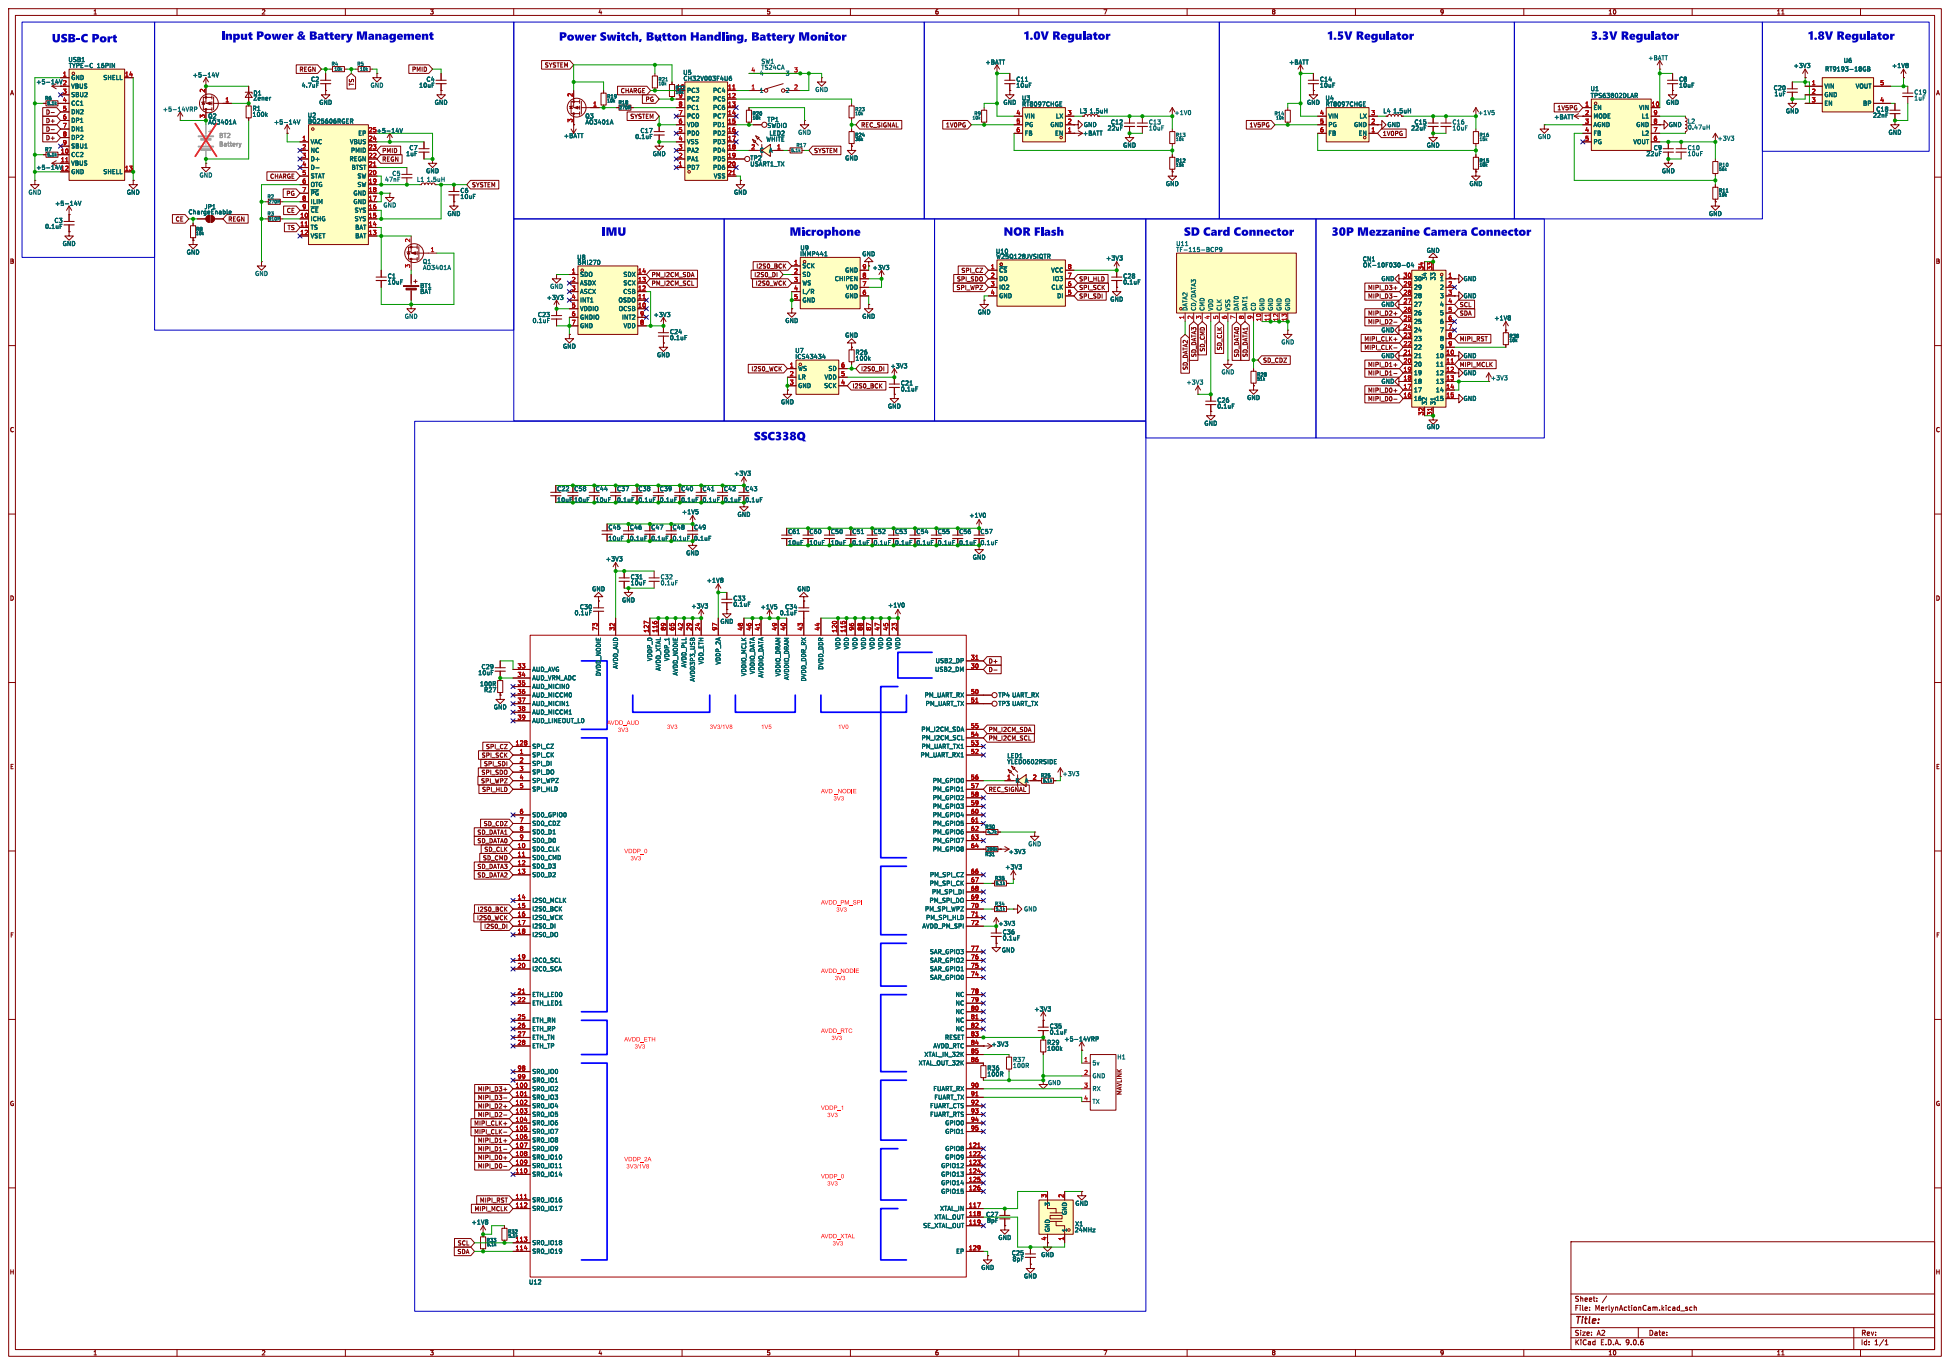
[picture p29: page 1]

4.7uFVAC 1 NC 2 D+ 3 D- 4 STAT 5 OTG 6 ~{PG} 7

VAC 1 NC 2 D+ 3 D- 4 STAT 5 OTG 6 ~{PG} 7

9 GND 10 GND 11 GND 12 GND 13 U11 TF-115-BCP9 +3V3 GND

+1V8 GND GND GND GND

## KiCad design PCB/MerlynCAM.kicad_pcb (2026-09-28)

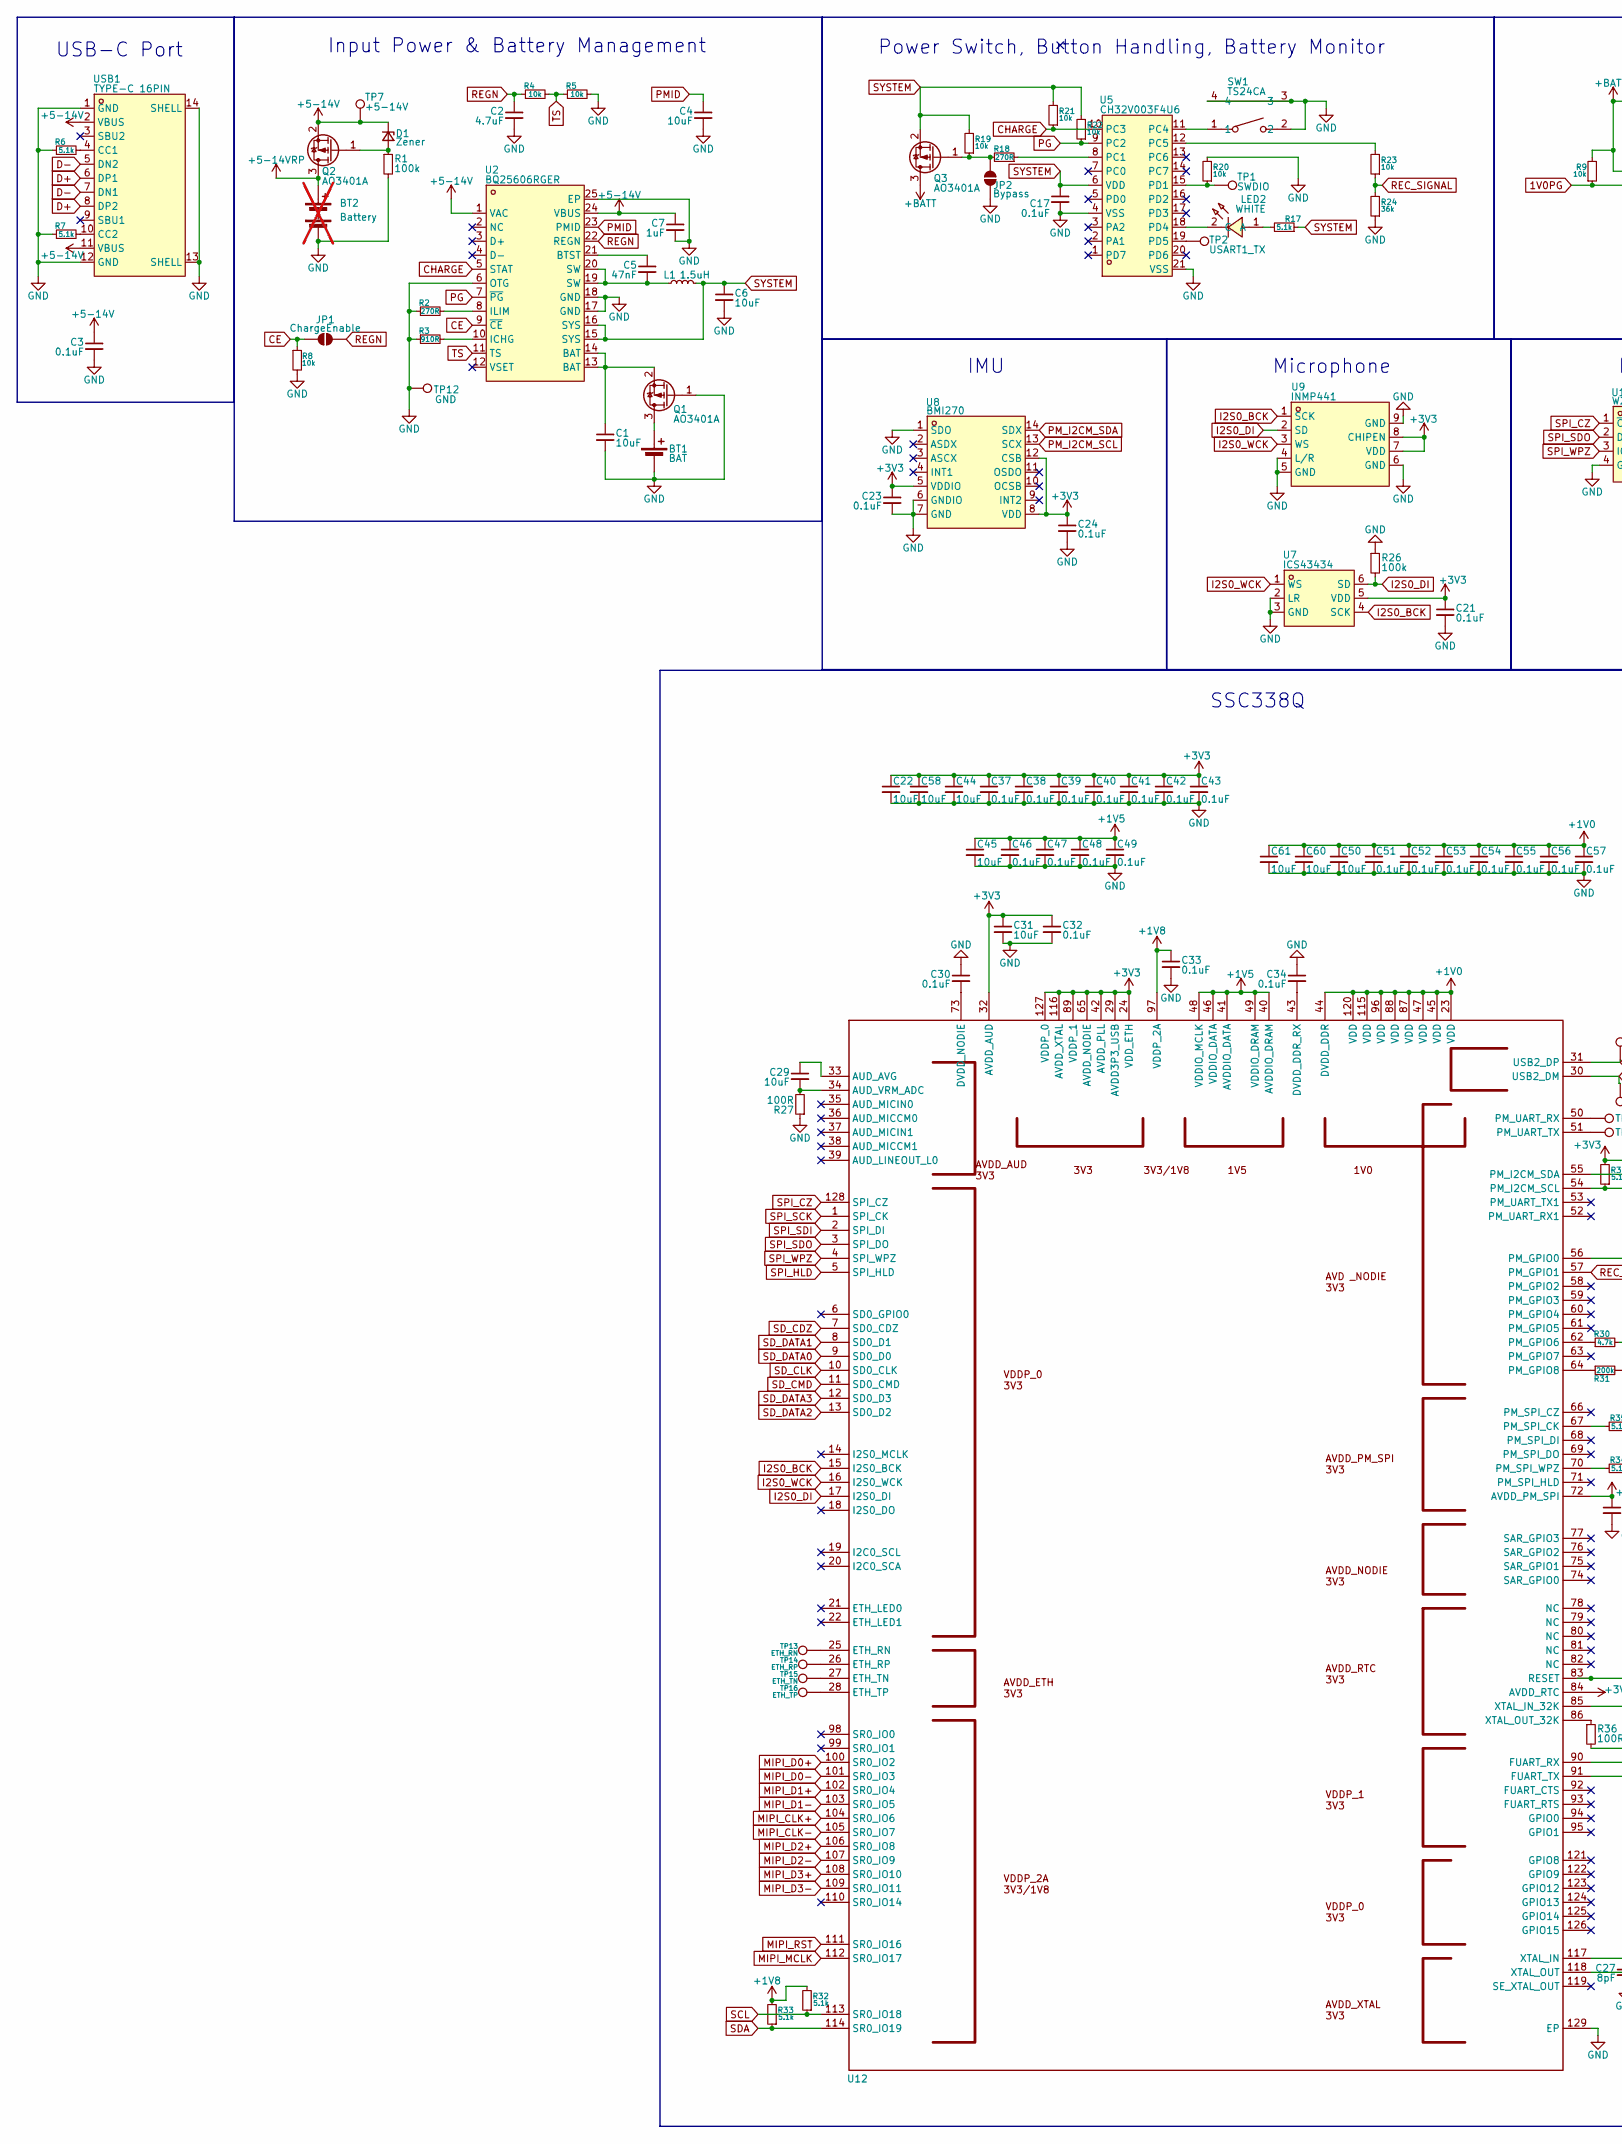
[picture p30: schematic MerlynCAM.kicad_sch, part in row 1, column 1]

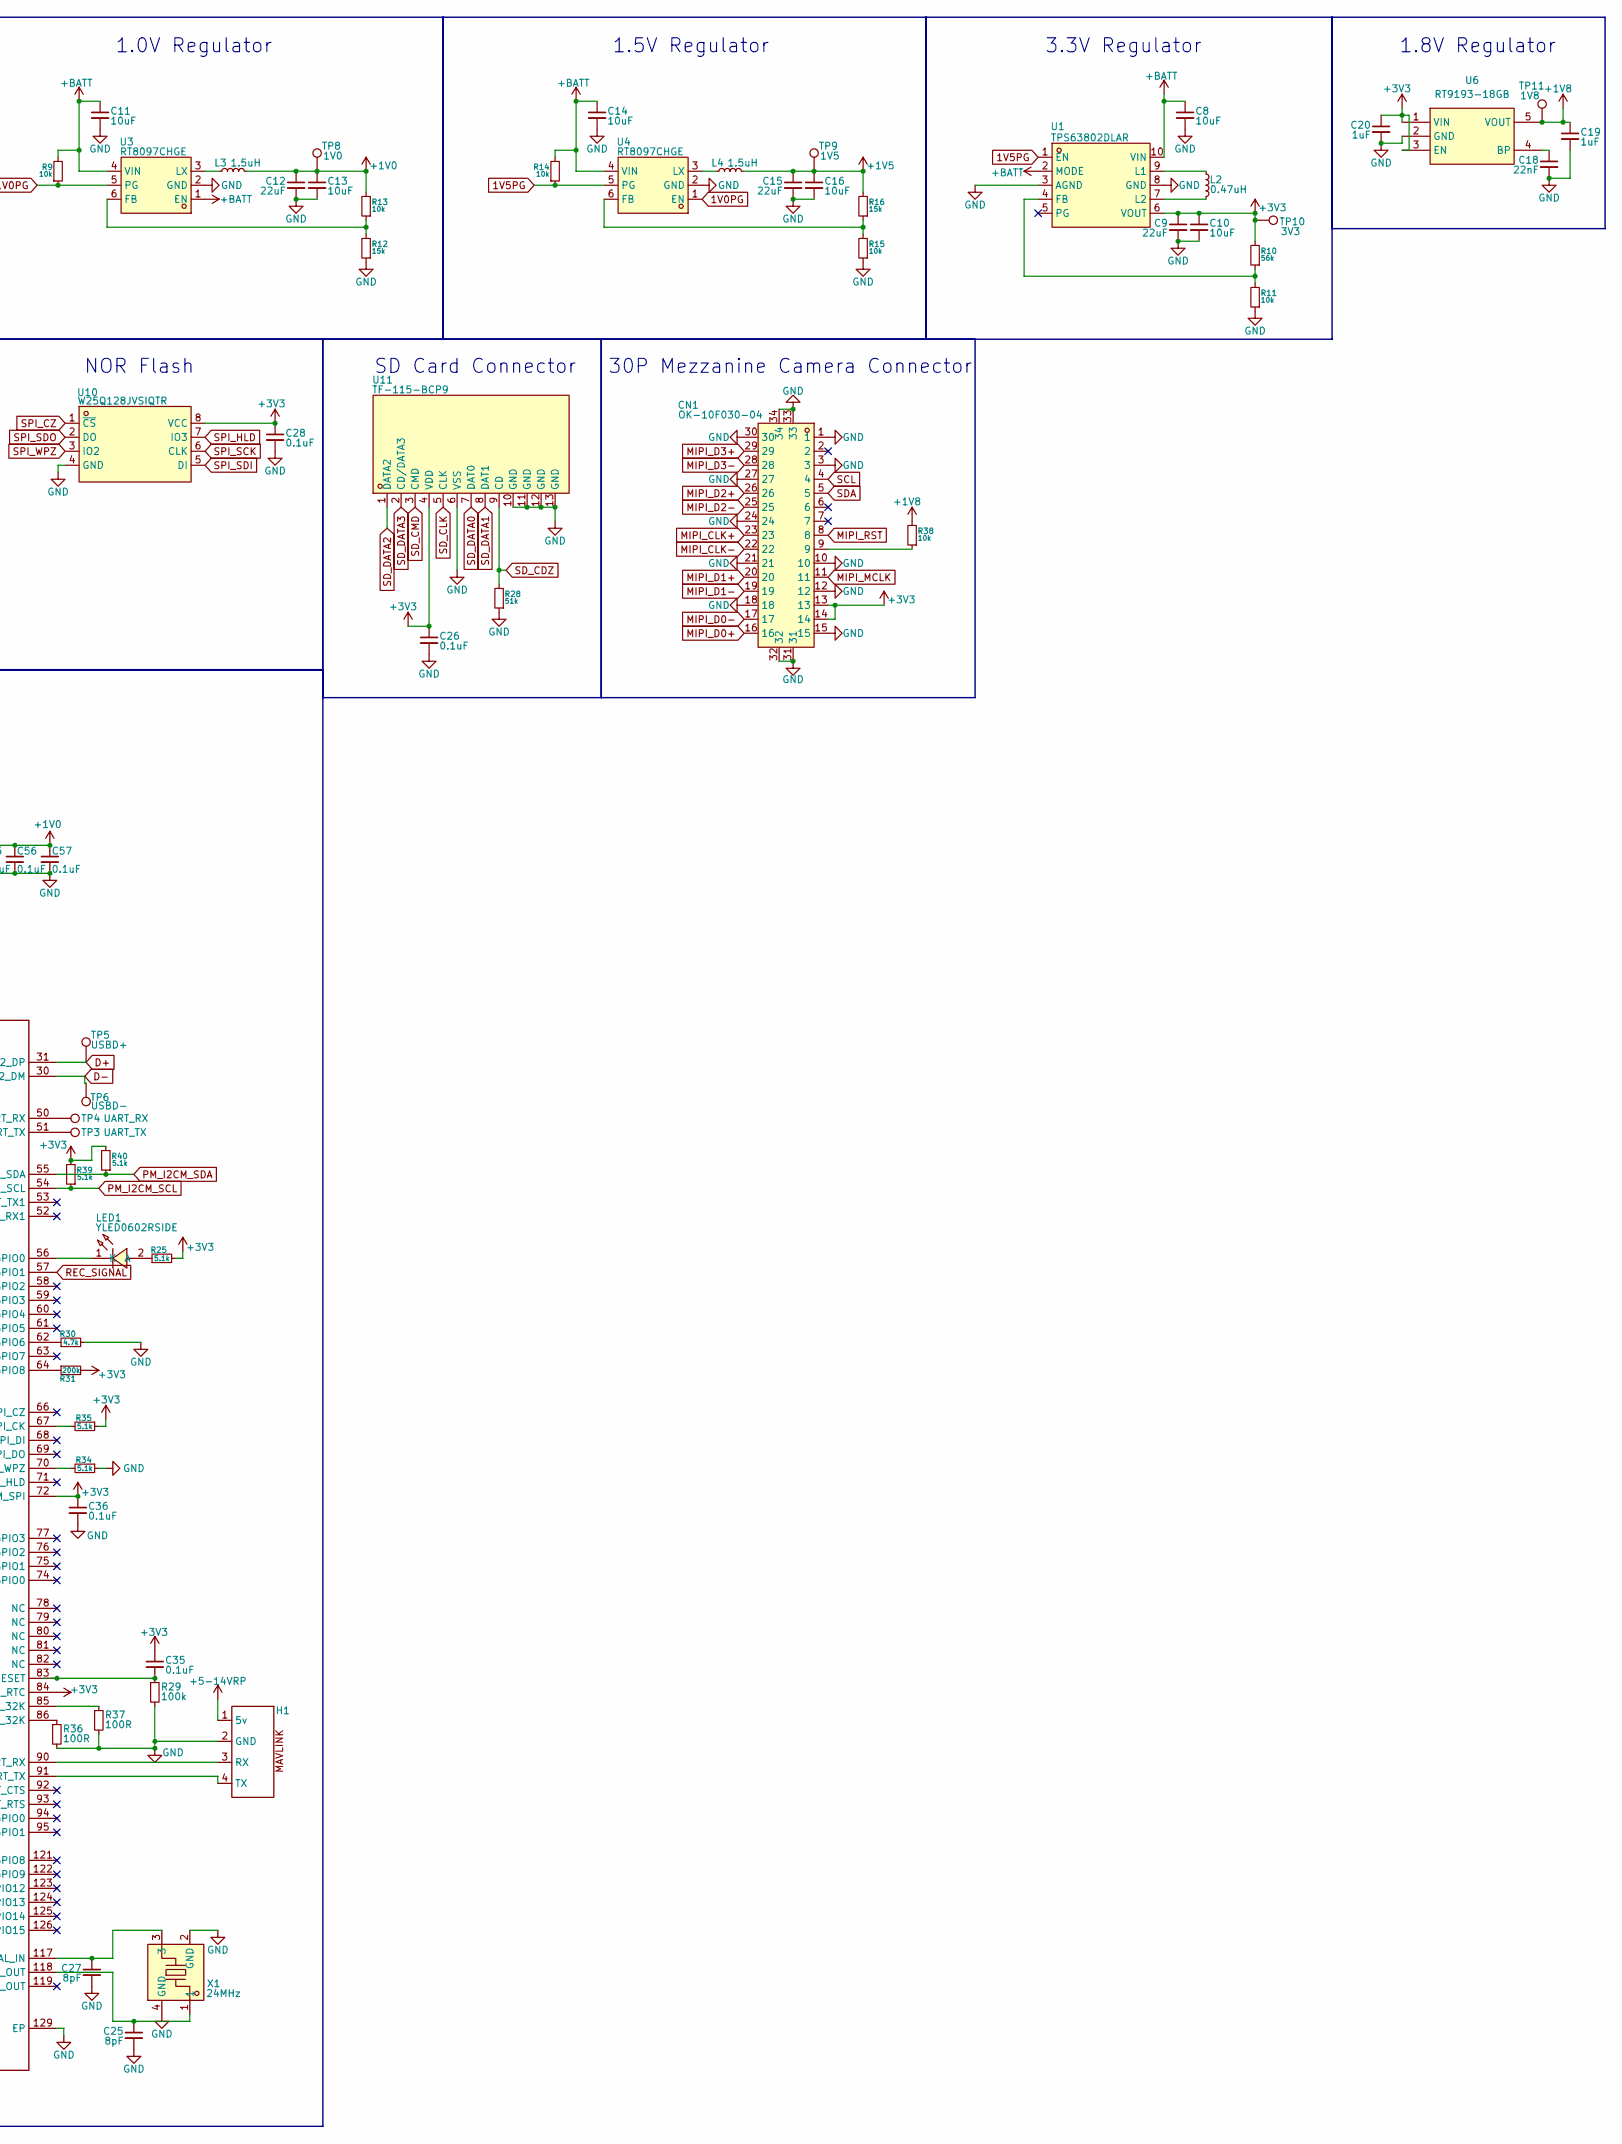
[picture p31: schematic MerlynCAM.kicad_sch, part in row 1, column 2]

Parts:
BT1: BAT; Battery
BT2: Battery; not fitted
C1, C4, C6, C8, C10, C11, C13, C14, C16, C22, C29, C31, C44, C45, C50, C58, C60, C61: 10uF; C_0603_1608Metric; LCSC Part C96446
C2: 4.7uF; C_0402_1005Metric; LCSC Part C23733
C3, C17, C21, C23, C24, C26, C28, C30, C32, C33, C34, C35, C36, C37, C38, C39, C40, C41, C42, C43, C46, C47, C48, C49, C51, C52, C53, C54, C55, C56, C57: 0.1uF; C_0402_1005Metric; LCSC Part C307331
C5: 47nF; C_0402_1005Metric; LCSC Part C272875
C7, C19, C20: 1uF; C_0402_1005Metric; LCSC Part C52923
C9, C12, C15: 22uF; C_0603_1608Metric; LCSC Part C59461
C18: 22nF; C_0402_1005Metric; LCSC Part C1532
C25, C27: 8pF; C_0402_1005Metric; LCSC Part C1578
CN1: OK-10F030-04; CONN-SMD_30P-P0.40_OK-10F030-04-A; MPN OK-10F030-04; LCSC Part C9900021743
D1: Zener; D_SOD-923; LCSC Part C414245
H1: JST_SH_SM04B-SRSS-TB_1x04-1MP_P1.00mm_Horizontal; LCSC Part C2845363
JP1: ChargeEnable; SolderJumper-2_P1.3mm_Open_TrianglePad1.0x1.5mm
JP2: Bypass; SolderJumper-2_P1.3mm_Open_TrianglePad1.0x1.5mm
L1, L3, L4: 1.5uH; L_Changjiang_FTC201610S; LCSC Part C5832343
L2: 0.47uH; L_Changjiang_FTC201610S; LCSC Part C5832340
LED1: YLED0602RSIDE; LED-SMD_L1.6-W1.1-RD; MPN YLED0602RSIDE; LCSC Part C49446796
LED2: WHITE; LED-SMD_L1.6-W1.1-R-RD_WHITE; MPN YLED0602WSIDE; LCSC Part C46635136
Q1, Q2, Q3: AO3401A; SOT-23; LCSC Part C15127
R1, R26, R29: 100k; R_0402_1005Metric; LCSC Part C25741
R2, R18: 270R; R_0402_1005Metric; LCSC Part C2909342
R3: 910R; R_0402_1005Metric; LCSC Part C2909392
R4, R5, R8, R9, R11, R13, R14, R15, R19, R20, R21, R22, R23, R38: 10k; R_0402_1005Metric; LCSC Part C25744
R6, R7, R17, R25, R32, R33, R34, R35, R39, R40: 5.1k; R_0402_1005Metric; LCSC Part C25905
R10: 56k; R_0402_1005Metric; LCSC Part C25796
R12, R16: 15k; R_0402_1005Metric; LCSC Part C25756
R24: 36k; R_0402_1005Metric; LCSC Part C2930004
R27, R36, R37: 100R; R_0402_1005Metric; LCSC Part C25076
R28: 51k; R_0402_1005Metric; LCSC Part C25794
R30: 4.7k; R_0402_1005Metric; LCSC Part C25900
R31: 200k; R_0402_1005Metric; LCSC Part C25764
SW1: TS24CA; SW-SMD_2P-TS24CA; MPN TS24CA; LCSC Part C393942
TP1: SWDIO; TestPoint
TP2: USART1_TX; TestPoint
TP3: UART_TX; TestPoint
TP4: UART_RX; TestPoint
TP5: USBD+; TestPoint
TP6: USBD-; TestPoint
TP7: +5-14V; TestPoint
TP8: 1V0; TestPoint
TP9: 1V5; TestPoint
TP10: 3V3; TestPoint
TP11: 1V8; TestPoint
TP12: GND; TestPoint
TP13: ETH_RN; TestPoint
TP14: ETH_RP; TestPoint
TP15: ETH_TN; TestPoint
TP16: ETH_TP; TestPoint
U1: TPS63802DLAR; VSON-10_L3.0-W2.0-P0.50-TL; MPN TPS63802DLAR; LCSC Part C2845237
U2: BQ25606RGER; VQFN-24_L4.0-W4.0-P0.50-TL-EP2.8; MPN BQ25606RGER; LCSC Part C374063
U3, U4: RT8097CHGE; SOT-23-6_L2.9-W1.6-P0.95-LS2.8-BL; MPN RT8097CHGE; LCSC Part C3031673
U5: CH32V003F4U6; QFN-20_L3.0-W3.0-P0.40-TL-EP1.7; MPN CH32V003F4U6; LCSC Part C5299908
U6: RT9193-18GB; SOT-23-5_L3.0-W1.7-P0.95-LS2.8-BR; MPN RT9193-18GB; LCSC Part C27416
U7: ICS43434; MIC-SMD_6P-L3.5-W2.7-P0.90-BL; MPN ICS-43434; LCSC Part C5656610
U8: BMI270; LGA-14_L3.0-W2.5-P0.50-BR; MPN BMI270; LCSC Part C2836813
U9: INMP441; MIC-SMD_INMP441; MPN INMP441; LCSC Part C5438445
U10: W25Q128JVSIQTR; SOIC-8_L5.3-W5.3-P1.27-LS8.0-BL; MPN W25Q128JVSIQ; LCSC Part C97521
U11: TF-115-BCP9; TF-SMD_TF-115-BCP9; MPN TF-115-BCP9; LCSC Part C720505
U12: QFN128_12.3_12.3
USB1: TYPE-C 16PIN; USB-C-SMD_TYPE-C-6PIN-2MD-073; LCSC Part C2765186
X1: 24MHz; CRYSTAL-SMD_4P-L2.0-W1.6-BL; MPN T201624MBBCE2X; LCSC Part C7303340

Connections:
1V0PG: R9.1, U3.5 (PG), U4.1 (EN)
1V5PG: R14.1, U1.1 (EN), U4.5 (PG)
+1V0: C12.1, C13.1, C50.1, C51.1, C52.1, C53.1, C54.1, C55.1, C56.1, C57.1, C60.1, C61.1, L3.2, R13.2, TP8.1, U12.23 (VDD), U12.44 (DVDD_DDR), U12.45 (VDD), U12.47 (VDD), U12.87 (VDD), U12.88 (VDD), U12.96 (VDD), U12.115 (VDD), U12.120 (VDD)
+1V5: C15.1, C16.1, C45.1, C46.1, C47.1, C48.1, C49.1, L4.2, R16.2, TP9.1, U12.40 (AVDDIO_DRAM), U12.41 (AVDDIO_DATA), U12.46 (VDDIO_DATA), U12.48 (VDDIO_MCLK), U12.49 (VDDIO_DRAM)
+1V8: C19.1, C33.1, R32.2, R33.2, R38.2, TP11.1, U6.5 (VOUT), U12.97 (VDDP_2A)
+3V3: C9.1, C10.1, C20.1, C21.1, C22.1, C23.1, C24.1, C26.1, C28.1, C31.1, C32.1, C35.1, C36.1, C37.1, C38.1, C39.1, C40.1, C41.1, C42.1, C43.1, C44.1, C58.1, CN1.13, CN1.14, R10.2, R25.2, R31.2, R35.1, R39.2, R40.2, TP10.1, U1.6 (VOUT), U6.1 (VIN), U6.3 (EN), U7.5 (VDD), U8.5 (VDDIO), U8.8 (VDD), U8.12 (CSB), U9.7 (VDD), U9.8 (CHIPEN), U10.8 (VCC), U11.4 (VDD), U12.24 (VDD_ETH), U12.29 (AVDD3P3_USB), U12.32 (AVDD_AUD), U12.42 (AVDD_PLL), U12.65 (AVDD_NODIE), U12.72 (AVDD_PM_SPI), U12.84 (AVDD_RTC), U12.89 (VDDP_1), U12.116 (AVDD_XTAL), U12.127 (VDDP_0)
+5-14V: C3.1, C7.1, D1.1 (K), Q2.2 (S), TP7.1, U2.1 (VAC), U2.24 (VBUS), USB1.2 (VBUS), USB1.11 (VBUS)
+5-14VRP: BT2.1 (+), H1.1 (5v), Q2.3 (D)
+BATT: C8.1, C11.1, C14.1, Q3.3 (D), R9.2, R14.2, U1.2 (MODE), U1.10 (VIN), U3.1 (EN), U3.4 (VIN), U4.4 (VIN)
CE: JP1.1 (A), R8.1, U2.9 (~CE)
CHARGE: R21.1, U2.5 (STAT), U5.10 (PC3)
D+: TP5.1, U12.31 (USB2_DP), USB1.6 (DP1), USB1.8 (DP2)
D-: TP6.1, U12.30 (USB2_DM), USB1.5 (DN2), USB1.7 (DN1)
GND: BT1.2 (-), BT2.2 (-), C1.2, C2.2, C3.2, C4.2, C6.2, C7.2, C8.2, C9.2, C10.2, C11.2, C12.2, C13.2, C14.2, C15.2, C16.2, C17.2, C18.2, C19.2, C20.2, C21.2, C22.2, C23.2, C24.2, C25.2, C26.2, C27.2, C28.2, C30.1, C31.2, C32.2, C33.2, C34.1, C36.2, C37.2, C38.2, C39.2, C40.2, C41.2, C42.2, C43.2, C44.2, C45.2, C46.2, C47.2, C48.2, C49.2, C50.2, C51.2, C52.2, C53.2, C54.2, C55.2, C56.2, C57.2, C58.2, C60.2, C61.2, CN1.1, CN1.3, CN1.10, CN1.12, CN1.15, CN1.18, CN1.21, CN1.24, CN1.27, CN1.30, CN1.31, CN1.32, CN1.33, CN1.34, H1.2 (GND), JP2.1 (A), Q1.1 (G), R1.2, R2.1, R3.1, R5.2, R6.1, R7.1, R8.2, R11.1, R12.1, R15.1, R20.2, R24.1, R26.1, R27.1, R28.1, R29.2, R30.2, R34.1, R36.2, R37.2, SW1.2, SW1.3, SW1.4, TP12.1, U1.3 (AGND), U1.8 (GND), U2.6 (OTG), U2.17 (GND), U2.18 (GND), U2.25 (EP), U3.2 (GND), U4.2 (GND), U5.4 (VSS), U5.21 (VSS), U6.2 (GND), U7.2 (LR), U7.3 (GND), U8.1 (SDO), U8.6 (GNDIO), U8.7 (GND), U9.4 (L/R), U9.5 (GND), U9.6 (GND), U9.9 (GND), U10.4 (GND), U11.6 (VSS), U11.10 (GND), U11.11 (GND), U11.12 (GND), U11.13 (GND), U12.129 (EP), USB1.1 (GND), USB1.12 (GND), USB1.13 (SHELL), USB1.14 (SHELL), X1.2 (GND), X1.4 (GND)
I2S0_BCK: U7.4 (SCK), U9.1 (SCK), U12.15 (I2S0_BCK)
I2S0_DI: R26.2, U7.6 (SD), U9.2 (SD), U12.17 (I2S0_DI)
I2S0_WCK: U7.1 (WS), U9.3 (WS), U12.16 (I2S0_WCK)
MIPI_CLK+: CN1.23, U12.104 (SR0_IO6)
MIPI_CLK-: CN1.22, U12.105 (SR0_IO7)
MIPI_D0+: CN1.16, U12.100 (SR0_IO2)
MIPI_D0-: CN1.17, U12.101 (SR0_IO3)
MIPI_D1+: CN1.20, U12.102 (SR0_IO4)
MIPI_D1-: CN1.19, U12.103 (SR0_IO5)
MIPI_D2+: CN1.26, U12.106 (SR0_IO8)
MIPI_D2-: CN1.25, U12.107 (SR0_IO9)
MIPI_D3+: CN1.29, U12.108 (SR0_IO10)
MIPI_D3-: CN1.28, U12.109 (SR0_IO11)
MIPI_MCLK: CN1.11, U12.112 (SR0_IO17)
MIPI_RST: CN1.8, U12.111 (SR0_IO16)
unnamed: BT1.1 (+), Q1.3 (D)
unnamed: C5.2, L1.1, U2.19 (SW), U2.20 (SW)
unnamed: CN1.9, R38.1
unnamed: D1.2 (A), Q2.1 (G), R1.1
unnamed: H1.3 (RX), U12.90 (FUART_RX)
unnamed: H1.4 (TX), U12.91 (FUART_TX)
unnamed: JP2.2 (B), Q3.1 (G), R18.2, R19.1
unnamed: LED1.2 (A), R25.1
unnamed: LED1.1 (K), U12.56 (PM_GPIO0)
unnamed: LED2.1 (A), R17.2
unnamed: LED2.2 (C), U5.18 (PD4)
unnamed: C1.1, Q1.2 (S), U2.13 (BAT), U2.14 (BAT)
unnamed: R10.1, R11.2, U1.4 (FB)
unnamed: L2.1, U1.9 (L1)
unnamed: L2.2, U1.7 (L2)
unnamed: C5.1, U2.21 (BTST)
unnamed: R3.2, U2.10 (ICHG)
unnamed: R2.2, U2.8 (ILIM)
unnamed: R12.2, R13.1, U3.6 (FB)
unnamed: L3.1, U3.3 (LX)
unnamed: R15.2, R16.1, U4.6 (FB)
unnamed: L4.1, U4.3 (LX)
unnamed: R18.1, U5.8 (PC1)
unnamed: SW1.1, U5.11 (PC4)
unnamed: R23.2, U5.12 (PC5)
unnamed: R20.1, TP1.1, U5.15 (PD1)
unnamed: TP2.1, U5.19 (PD5)
unnamed: C18.1, U6.4 (BP)
unnamed: C29.1, U12.33 (AUD_AVG)
unnamed: C29.2, R27.2, U12.34 (AUD_VRM_ADC)
unnamed: C34.2, U12.43 (DVDD_DDR_RX)
unnamed: C30.2, U12.73 (DVDD_NODIE)
unnamed: TP13.1, U12.25 (ETH_RN)
unnamed: TP14.1, U12.26 (ETH_RP)
unnamed: TP15.1, U12.27 (ETH_TN)
unnamed: TP16.1, U12.28 (ETH_TP)
unnamed: R30.1, U12.62 (PM_GPIO6)
unnamed: R31.1, U12.64 (PM_GPIO8)
unnamed: R35.2, U12.67 (PM_SPI_CK)
unnamed: R34.2, U12.70 (PM_SPI_WPZ)
unnamed: TP4.1, U12.50 (PM_UART_RX)
unnamed: TP3.1, U12.51 (PM_UART_TX)
unnamed: C35.2, R29.1, U12.83 (RESET)
unnamed: C27.1, U12.117 (XTAL_IN), X1.3
unnamed: R37.1, U12.85 (XTAL_IN_32K)
unnamed: C25.1, U12.118 (XTAL_OUT), X1.1
unnamed: R36.1, U12.86 (XTAL_OUT_32K)
unnamed: R6.2, USB1.4 (CC1)
unnamed: R7.2, USB1.10 (CC2)
PG: R22.1, U2.7 (~PG), U5.9 (PC2)
PMID: C4.1, U2.23 (PMID)
PM_I2CM_SCL: R39.1, U8.13 (SCX), U12.54 (PM_I2CM_SCL)
PM_I2CM_SDA: R40.1, U8.14 (SDX), U12.55 (PM_I2CM_SDA)
REC_SIGNAL: R23.1, R24.2, U12.57 (PM_GPIO1)
REGN: C2.1, JP1.2 (B), R4.1, U2.22 (REGN)
SCL: CN1.4, R32.1, U12.113 (SR0_IO18)
SDA: CN1.5, R33.1, U12.114 (SR0_IO19)
SD_CDZ: R28.2, U11.9 (CD), U12.7 (SD0_CDZ)
SD_CLK: U11.5 (CLK), U12.10 (SD0_CLK)
SD_CMD: U11.3 (CMD), U12.11 (SD0_CMD)
SD_DATA0: U11.7 (DAT0), U12.9 (SD0_D0)
SD_DATA1: U11.8 (DAT1), U12.8 (SD0_D1)
SD_DATA2: U11.1 (DATA2), U12.13 (SD0_D2)
SD_DATA3: U11.2 (CD/DATA3), U12.12 (SD0_D3)
SPI_CZ: U10.1 (~CS), U12.128 (SPI_CZ)
SPI_HLD: U10.7 (IO3), U12.5 (SPI_HLD)
SPI_SCK: U10.6 (CLK), U12.1 (SPI_CK)
SPI_SDI: U10.5 (DI), U12.2 (SPI_DI)
SPI_SDO: U10.2 (DO), U12.3 (SPI_DO)
SPI_WPZ: U10.3 (IO2), U12.4 (SPI_WPZ)
SYSTEM: C6.1, C17.1, L1.2, Q3.2 (S), R17.1, R19.2, R21.2, R22.2, U2.15 (SYS), U2.16 (SYS), U5.6 (VDD)
TS: R4.2, R5.1, U2.11 (TS)

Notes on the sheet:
30P Mezzanine Camera Connector
USB-C Port
1.5V Regulator
3.3V Regulator
Power Switch, Button Handling, Battery Monitor
1.8V Regulator
Input Power & Battery Management
NOR Flash
Microphone
SSC338Q
SD Card Connector
1.0V Regulator
IMU

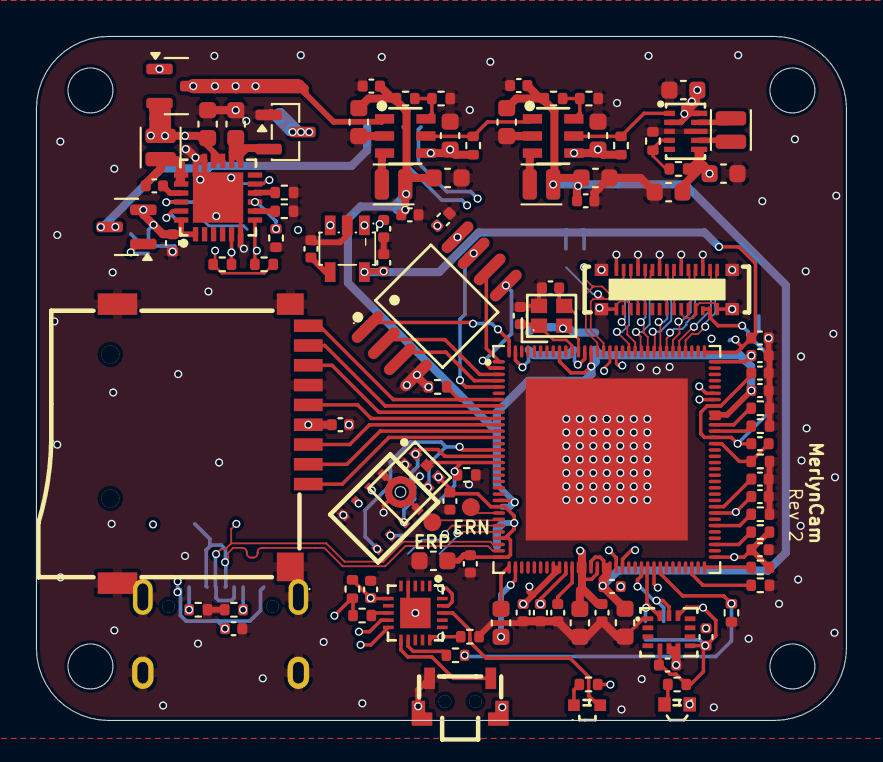
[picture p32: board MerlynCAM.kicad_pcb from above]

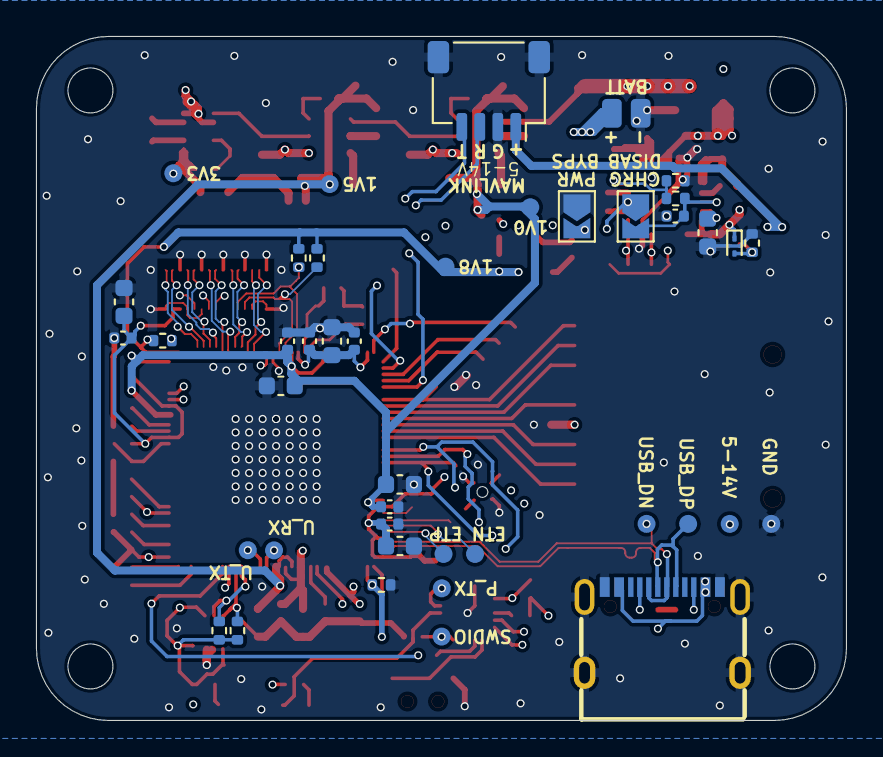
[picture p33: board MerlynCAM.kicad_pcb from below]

Board: 4 copper layers, 45.0 x 38.0 mm, 146 parts (42 on the bottom side), 101 nets.

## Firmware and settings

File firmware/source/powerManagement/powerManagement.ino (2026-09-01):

#include "ch32v003fun.h"
#include <stdbool.h>

// --- Pin Definitions ---
#define PIN_MOSFET   1 // PC1 (Output, Low = ON)
#define PIN_PG       2 // PC2 (Input, Low = Power applied)
#define PIN_STATUS   3 // PC3 (Input)
#define PIN_BTN      4 // PC4 (Input, Low = Pressed)
#define PIN_RECORD   5 // PC5 (Output)
#define PIN_LED      4 // PD4 (Output, Low = ON)

// --- Battery Thresholds (mV) ---
#define BATT_95 4100
#define BATT_80 3830
#define BATT_60 3700
#define BATT_40 3610
#define BATT_20 3500
#define BATT_5  3200

// --- System States ---
typedef enum {
    STATE_STANDBY,
    STATE_OFF_WAKE,
    STATE_ON
} SystemState;

SystemState current_state = STATE_STANDBY;
bool is_recording = false;
bool is_charging = false;
uint32_t last_batt_blink = 0; // Moved to global scope for the Arduino loop()

// --- Hardware Control Functions ---
void led_on()  { GPIOD->BCR = (1 << PIN_LED); }  // Drive Low
void led_off() { GPIOD->BSHR = (1 << PIN_LED); } // Drive High
void mosfet_on()  { GPIOC->BCR = (1 << PIN_MOSFET); }  // Drive Low
void mosfet_off() { GPIOC->BSHR = (1 << PIN_MOSFET); } // Drive High
void rec_high() { GPIOC->BSHR = (1 << PIN_RECORD); }
void rec_low()  { GPIOC->BCR = (1 << PIN_RECORD); }

bool btn_pressed() { return !(GPIOC->INDR & (1 << PIN_BTN)); }
bool pg_active()   { return !(GPIOC->INDR & (1 << PIN_PG)); }
bool status_high() { return (GPIOC->INDR & (1 << PIN_STATUS)); }

// --- Hardware Initialization ---
void init_hardware() {
    // Enable Clocks for Port C, Port D, ADC1, and AFIO
    RCC->APB2PCENR |= RCC_APB2Periph_GPIOC | RCC_APB2Periph_GPIOD | RCC_APB2Periph_ADC1 | RCC_APB2Periph_AFIO;

    // Configure PC1 (MOSFET), PC5 (RECORD) as Push-Pull Outputs
    GPIOC->CFGLR &= ~(0xF << (4 * PIN_MOSFET) | 0xF << (4 * PIN_RECORD));
    GPIOC->CFGLR |= (0x3 << (4 * PIN_MOSFET) | 0x3 << (4 * PIN_RECORD)); // 50MHz Push-Pull
    mosfet_off();
    rec_low();

    // Configure PD4 (LED) as Push-Pull Output
    GPIOD->CFGLR &= ~(0xF << (4 * PIN_LED));
    GPIOD->CFGLR |= (0x3 << (4 * PIN_LED));
    led_off();

    // Configure PC2 (PG), PC3 (STATUS), PC4 (BTN) as Inputs with Pull-Up
    GPIOC->CFGLR &= ~(0xF << (4 * PIN_PG) | 0xF << (4 * PIN_STATUS) | 0xF << (4 * PIN_BTN));
    GPIOC->CFGLR |= (0x8 << (4 * PIN_PG) | 0x8 << (4 * PIN_STATUS) | 0x8 << (4 * PIN_BTN)); // Input with pull-up/down
    GPIOC->OUTDR |= (1 << PIN_PG) | (1 << PIN_STATUS) | (1 << PIN_BTN); // Set to Pull-Up

    // Configure EXTI for PC2 (PG) and PC4 (BTN) to wake from Standby
    AFIO->EXTICR = (2 << (PIN_PG * 2)) | (2 << (PIN_BTN * 2)); // Assign Port C to EXTI2 and EXTI4
    EXTI->INTENR |= (1 << PIN_PG) | (1 << PIN_BTN);            // Enable EXTI lines
    EXTI->FTENR |= (1 << PIN_PG) | (1 << PIN_BTN);             // Falling edge trigger
}

// --- ADC & Battery Functions ---
void init_adc() {
    // ADC Setup for Channel 8 (Internal 1.2V Vref)
    ADC1->CTLR2 |= ADC_ADON; // Turn on ADC
    ADC1->RSQR3 = 8;         // Select Channel 8
    ADC1->SAMPTR2 = (7 << (3 * 8)); // Max sample time
    
    // Reset Calibration
    ADC1->CTLR2 |= ADC_RSTCAL;
    while(ADC1->CTLR2 & ADC_RSTCAL);
    // Start Calibration
    ADC1->CTLR2 |= ADC_CAL;
    while(ADC1->CTLR2 & ADC_CAL);
}

uint32_t get_battery_mv() {
    ADC1->CTLR2 |= ADC_SWSTART; // Start Conversion
    while(!(ADC1->STATR & ADC_EOC)); // Wait for End Of Conversion
    uint32_t adc_val = ADC1->RDATAR;
    
    // VDD (Battery) = (1.2V * 1023) / ADC_Reading
    if(adc_val == 0) return 0;
    return (1200 * 1023) / adc_val;
}

// --- LED Sequences ---
void blink_led(int count, uint32_t ms_on, uint32_t ms_off) {
    for(int i = 0; i < count; i++) {
        led_on();
        Delay_Ms(ms_on);
        led_off();
        if(i < count - 1) Delay_Ms(ms_off);
    }
}

void show_battery_level(uint32_t batt_mv) {
    if(batt_mv < BATT_5) {
        blink_led(3, 100, 100);
    } else if(batt_mv < BATT_20) {
        blink_led(1, 300, 300);
    } else if(batt_mv < BATT_40) {
        blink_led(2, 300, 300);
    } else if(batt_mv < BATT_60) {
        blink_led(3, 300, 300);
    } else if(batt_mv < BATT_80) {
        blink_led(4, 300, 300);
    } else {
        blink_led(4, 300, 300);
        Delay_Ms(300);
        blink_led(3, 100, 100);
    }
}

// --- Shutdown Sequence ---
void shutdown_sequence() {
    is_recording = false;
    rec_low();
    
    // 10Hz 33% duty cycle for 5 seconds to SSC338Q
    // 10Hz = 100ms period. 33% = 33ms HIGH, 67ms LOW.
    for(int i = 0; i < 50; i++) {
        rec_high();
        Delay_Ms(33);
        rec_low();
        Delay_Ms(67);
    }
    
    mosfet_off();
    current_state = STATE_STANDBY;
}

// ==========================================
// ARDUINO ENTRY POINTS (setup & loop)
// ==========================================

void setup() {
    init_hardware();
    init_adc();

    // Check Cold Boot State (External power applied, no battery)
    if(pg_active() && status_high()) {
        mosfet_on();
        rec_high();
        is_recording = true;
        current_state = STATE_ON;
    }
}

void loop() {
    uint32_t now = millis(); // using the Arduino Core's built-in millis()
    uint32_t batt_mv = get_battery_mv();

    switch(current_state) {
        
        case STATE_STANDBY: { 
            // Deep Sleep (retains RAM, continues code below on wake-up)
            PWR->CTLR &= ~PWR_CTLR_PDDS; // Clear PDDS for normal Deep Sleep
            PFIC->SCTLR |= (1<<2);       // Set Sleepdeep bit
            __WFI();                     // Wait For Interrupt (Wakes on PC2 or PC4)
            
            // --- Wake Up Handling ---
            // (Clocks are automatically restored from deep sleep)
            
            // Wake logic evaluation
            if(btn_pressed()) {
                current_state = STATE_OFF_WAKE;
            } else if(pg_active() && !status_high()) {
                is_charging = true;
            }
            break;
        }

        case STATE_OFF_WAKE: { 
            // Wait for button release to show battery
            while(btn_pressed());
            show_battery_level(batt_mv);

            // Wait for sequence: Press within 1000ms, then hold for 2s
            uint32_t seq_start = millis();
            bool sequence_success = false;

            while(millis() - seq_start < 1000) {
                if(btn_pressed()) {
                    uint32_t hold_start = millis();
                    bool hold_failed = false;

                    // Check for 2-second hold
                    while(millis() - hold_start < 2000) {
                        if(!btn_pressed()) {
                            hold_failed = true;
                            break;
                        }
                        // Rapid blink during hold
                        if((millis() / 100) % 2 == 0) led_on();
                        else led_off();
                    }
                    
                    led_off(); // Ensure LED is off before transition

                    if(!hold_failed) {
                        if(batt_mv >= BATT_5) {
                            sequence_success = true;
                            led_on();
                            mosfet_on();
                            while(btn_pressed()); // Wait for release
                            led_off();
                        } else {
                            // Battery too low
                            blink_led(3, 100, 100);
                        }
                    }
                    break; 
                }
            }

            if(sequence_success) {
                current_state = STATE_ON;
                last_batt_blink = millis();
            } else {
                current_state = STATE_STANDBY;
            }
            break;
        }

        case STATE_ON: { 
            // Non-blocking battery percentage flash every 3500ms
            if(now - last_batt_blink >= 3500 && !btn_pressed()) {
                show_battery_level(batt_mv);
                last_batt_blink = millis();
            }

            // Handle Button Holds while ON
            if(btn_pressed()) {
                uint32_t hold_start = millis();
                bool recording_toggled = false;

                while(btn_pressed()) {
                    uint32_t held_time = millis() - hold_start;

                    // 4 Seconds: Turn Off Sequence
                    if(held_time >= 4000) {
                        blink_led(2, 300, 300);
                        shutdown_sequence();
                        break; 
                    }
                    // > 2 Seconds: Rapid warning blink
                    else if(held_time >= 2000) {
                        if((millis() / 100) % 2 == 0) led_on();
                        else led_off();
                    }
                    // 1-2 Seconds: Ready to toggle recording (triggers on release)
                    else if(held_time >= 1000 && !recording_toggled) {
                        recording_toggled = true; // Mark as ready to toggle
                    }
                }

                led_off(); // Ensure off upon release

                // If released between 1 and 2 seconds, toggle recording
                if(recording_toggled && current_state == STATE_ON) {
                    is_recording = !is_recording;
                    if(is_recording) rec_high();
                    else rec_low();
                }
            }
            break;
        }
    }

    // Charging logic update while in Standby loop (if not handled by EXTI waking)
    if(current_state == STATE_STANDBY) {
        if(!pg_active() || status_high()) {
            if(is_charging) {
                is_charging = false;
                led_off();
            }
        } else {
            // If charging, blink slowly
            is_charging = true;
            if((millis() / 1000) % 2 == 0) led_on();
            else led_off();
        }
    }
}

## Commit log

2026-09-09 update BOM and price
    Choose a smaller stencil (65x58mm), it will reduce stencil size and shipping costs. Also remove any other unrelated PCB in the cart and use JLCONE app to use $2 PCB deal
    [BOM.csv]
2026-09-11 Update microphone footprint
    Changed PTH to NPTH, increased mic hole diameter from 0.25mm to 0.6mm
    [MerlynCAM.kicad_pcb]
2026-09-28 Updated PCB to Rev 2
    [MerlynCAM.kicad_pcb, MerlynCAM.kicad_sch, bom.csv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]
2026-10-08 update power controller firmware
2026-10-08 Firmware update
    Upgraded OpenIPC firmware, power management firmware, added action cam recorder task firmware for opnipc
2026-10-10 update actioncam.c and binary to fix gyro logging delay
